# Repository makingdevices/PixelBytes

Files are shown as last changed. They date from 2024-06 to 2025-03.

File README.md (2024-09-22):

<!-- Improved compatibility of back to top link: See: https://github.com/othneildrew/Best-README-Template/pull/73 -->

<!--
*** Thanks for checking out the Best-README-Template. If you have a suggestion
*** that would make this better, please fork the repo and create a pull request
*** or simply open an issue with the tag "enhancement".
*** Don't forget to give the project a star!
*** Thanks again! Now go create something AMAZING! :D
-->

<!-- PROJECT SHIELDS -->
<!--
*** I'm using markdown "reference style" links for readability.
*** Reference links are enclosed in brackets [ ] instead of parentheses ( ).
*** See the bottom of this document for the declaration of the reference variables
*** for contributors-url, forks-url, etc. This is an optional, concise syntax you may use.
*** https://www.markdownguide.org/basic-syntax/#reference-style-links
-->
[][ig-url]
[][sponsor-url]
[][stars-url]
[][issues-url]
[][linkedin-url]

<!-- PROJECT LOGO -->
<br />
<div align="center">
  <a href="https://makingdevices.com/links/">
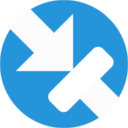
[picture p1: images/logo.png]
    
  </a>

<h3 align="center">Making Devices</h3>

  <p align="center">
    Open Source projects where we struggle with engineering, electronics, coding and who knows what else... Pixel Bytes is an evolution of my previous 8-bit console. The new version is based in the STM32F103CB with IC Leds for a colorwide screen and new power to code new games. 
  </p>
</div>

<!-- TABLE OF CONTENTS -->
<details>
  <summary>Table of Contents</summary>
  <ol>
    <li>
      <a href="#about-the-project">About The Project</a>
      <ul>
        <li><a href="#built-with">Built With</a></li>
      </ul>
    </li>
    <li>
      <a href="#Build-one">Build one</a>
      <ul>
      </ul>
    </li>
    <li><a href="#usage">Usage</a></li>
    <li><a href="#roadmap">Roadmap</a></li>
    <li><a href="#license">License</a></li>
    <li><a href="#contact">Contact</a></li>
    <li><a href="#Sponsor">Sponsor</a></li>
  </ol>
</details>

<!-- ABOUT THE PROJECT -->
## About The Project

[Bytes Counter Shot](https://makingdevices.com/)

PixelBytes was born in colaboration with Wurth Elektronik and their new RGB IC LEDs. They sent me a bunch of them to test so I though of making a proper evolution of my previous video console. For this time, I wanted to test a new manufacturer for the microcontroller, so it is my first big project working with the STM32. Hopefully it will help to develop new exciting games as it is arduino-compatible. On top of that, I decided to add a giroscope sensor so we can add more ways to have fun within the gaming experience ;). 

The project is divided into two steps: 
1. The first one is the PixelBytesDisplay, which is a matrix of 13x21 IC LEDs divided in 6 strings. 
2. The second part is the host board, which will mount the microcontroller and all the battery and sensors.

<p align="right">(<a href="#readme-top">back to top</a>)</p>

### Built With

[][PIC-url]
[][Arduino-url]
[][kicad-url]
[][sponsor-url-wurth]
[][sponsor-url]

<p align="right">(<a href="#readme-top">back to top</a>)</p>

<!-- GETTING STARTED -->

## Build one
The project is yet to be finished. Should you want to reproduce it, be careful. 

1. Get the gerber files for the latest version: [Pixel Bytes Display V0.1](/Gerber/Display/pixelbytesdisplay-v0.1) 
2. Get the gerber files for the latest version: [Pixel Bytes Host V0.1](/Gerber/Host/PixelBytesHostV0.1) 
3. Send them to a PCB manufacturer ([Our Sponsor is PCBWAY][sponsor-url])

YET TO BE COMPLETED.

<p align="right">(<a href="#readme-top">back to top</a>)</p>

<!-- USAGE EXAMPLES -->
## Usage

Instructions of use:

- When turn on, a menu is shown to select between the available games.
- Once you have played a game, a score board will appear everytime you open the game.
- You have a setting menu to turn-off the init splash and the sound.
- If you leave the console one minute without touching the buttons, it will turn into sleep mode.
- Enjoy!

<p align="right">(<a href="#readme-top">back to top</a>)</p>

<!-- ROADMAP -->
## Roadmap

- [x] Validate the Pixel Bytes Display
- [x] Assembly a prototype with the F103 Board
- [ ] Order/Assembly the Pixel Bytes Host
- [ ] Develop the firmware
  - [ ] Develop the library for the screen
  - [ ] Develop the menu 
  - [ ] Develop Snake
  - [ ] Develop Arkanoid
  - [ ] Develop Tetris
  - [ ] Develop a game that uses the gyro sensor
  - [ ] Score board
  - [ ] Sleep Mode
- [ ] Validate the complete design (host + display board)

See the [open issues](https://github.com/makingdevices/PixelBytes/issues) for a full list of proposed features (and known issues).

State: Project <b>ONGOING</b> - 22/09/2024

Priority: <b>High</b>

<p align="right">(<a href="#readme-top">back to top</a>)</p>

<!-- LICENSE -->
## License

Distributed under three licenses:
- [Hardware](/License/HW_cern_ohl_s_v2.pdf)
- [Software](/License/SW_GPLv3.0.txt)
- [Documentation](/License/Documentation_CC-BY-SA-4.0.txt)

OSHWA License: Not Finished

[GPL v3 License][license-url] 
<p align="right">(<a href="#readme-top">back to top</a>)</p>

<!-- CONTACT -->
## Contact

Making Devices - [@MakingDevices](https://www.instagram.com/makingdevices/)

Project Link: [https://github.com/makingdevices/PixelBytes](https://github.com/makingdevices/PixelBytes)

Other Links: [LinkTree](https://makingdevices.com/links/)

<!-- Sponsor -->
## Sponsors
## PCBWAY

[PCBWAY](https://www.pcbway.com/?from=makingdevices) is the most professional PCB manufacturer for prototyping and low-volume production to work with in the world. With more than a decade in the field, They are committed to meeting the needs of their customers from different industries in terms of quality, delivery, cost-effectiveness and any other demanding requests. As Sponsor of Making Devices, they will be in charge of all the PCBs for MDV, allowing both of us to grow together in a long term partnership. We hope you take them into account for your both personal and professional prototypes or products.

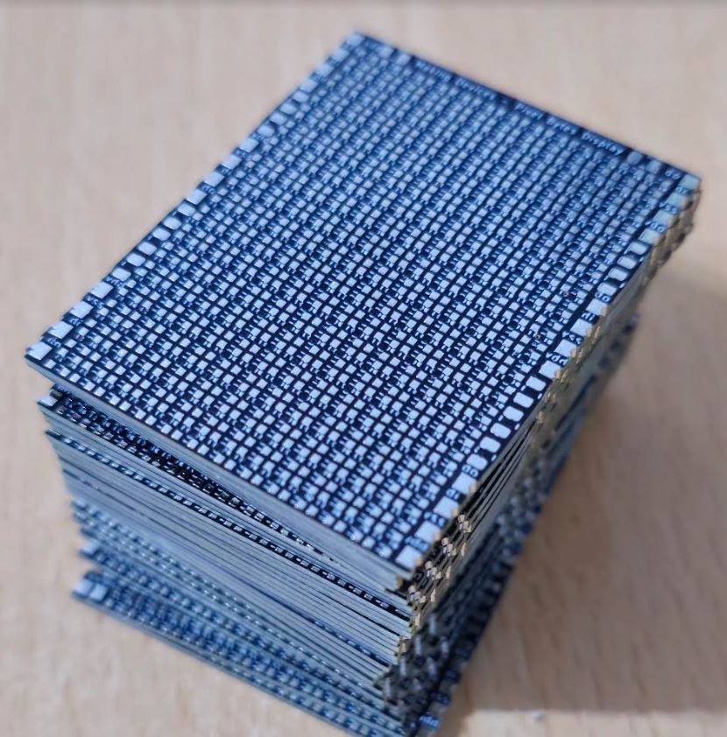
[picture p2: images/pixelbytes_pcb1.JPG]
[][sponsor-url]
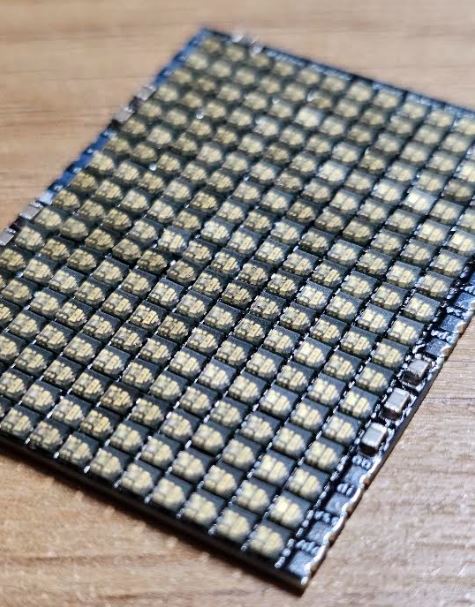
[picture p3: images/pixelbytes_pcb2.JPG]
[][sponsor-url]

## Würth Elektronik

[Wurth Elektronik](https://www.we-online.com/en) is one of the leading manufacturers of electronic and electromechanical components. The best I can say about them is to show you some pictures: All the LEDs from the board are from them. They also have buttons, resistors and capacitors that we use in all our PCBs. They also have some design kits with a lifetime refill which are amazing for makers and business so you can prototype on the go with a huge variety of components!

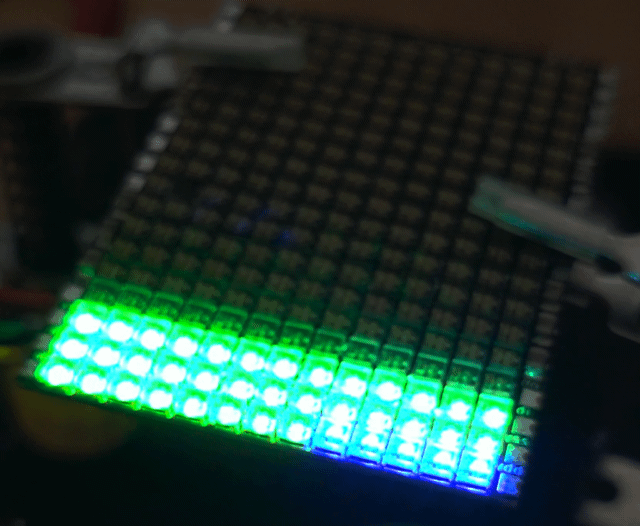
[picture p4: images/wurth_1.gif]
[][sponsor-url-wurth]
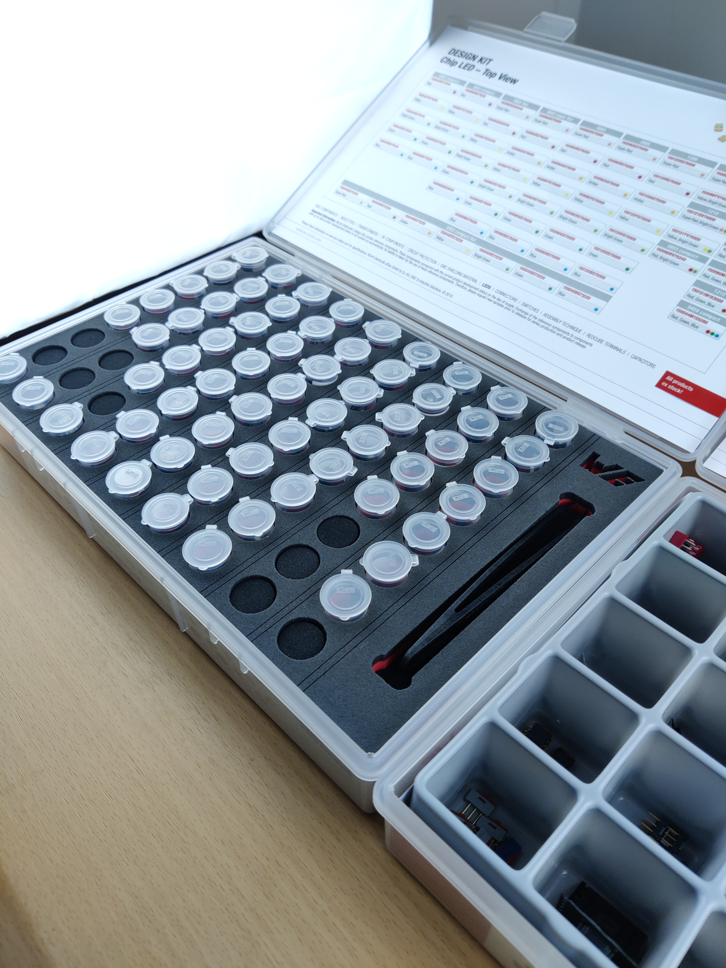
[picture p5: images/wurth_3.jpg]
[][sponsor-url-wurth]

<p align="right">(<a href="#readme-top">back to top</a>)</p>

<!-- MARKDOWN LINKS & IMAGES -->
<!-- https://www.markdownguide.org/basic-syntax/#reference-style-links -->
[contributors-shield]: https://img.shields.io/github/contributors/makingdevices/PixelBytes.svg?style=for-the-badge
[contributors-url]: https://github.com/makingdevices/PixelBytes/graphs/contributors
[forks-shield]: https://img.shields.io/github/forks/makingdevices/PixelBytes.svg?style=for-the-badge
[forks-url]: https://github.com/makingdevices/PixelBytes/network/members
[stars-shield]: https://img.shields.io/github/stars/makingdevices/PixelBytes.svg?style=for-the-badge
[stars-url]: https://github.com/makingdevices/PixelBytes/stargazers
[issues-shield]: https://img.shields.io/github/issues/makingdevices/PixelBytes.svg?style=for-the-badge
[issues-url]: https://github.com/makingdevices//PixelBytes/issues
[license-shield]: /images/license.png
[license-url]: https://github.com/makingdevices/PixelBytes/tree/main/License
[linkedin-shield]: https://img.shields.io/badge/-LinkedIn-black.svg?style=for-the-badge&logo=linkedin&colorB=555
[linkedin-url]: https://www.linkedin.com/company/making-devices/
[sponsor-shield]: https://img.shields.io/badge/SPONSOR-PCBWAY-black.svg?style=for-the-badge&colorB=1200
[sponsor-url]: https://www.pcbway.com/?from=makingdevices
[sponsor-screenshot]: /images/PCB_sponsor.png
[sponsor-pcb-1]: /images/pixelbytes_pcb1.JPG
[sponsor-pcb-2]: /images/pixelbytes_pcb2.JPG
[sponsor-wurth-1]: /images/wurth_1.gif
[sponsor-wurth-3]: /images/wurth_3.jpg
[sponsor-url-wurth]: https://www.we-online.com/en
[product-screenshot]: images/screenshot.gif
[PIC]: https://img.shields.io/badge/STM32F103-0000D1?style=for-the-badge
[PIC-url]: https://www.st.com/en/microcontrollers-microprocessors/stm32f103.html
[kicad-shield]: https://img.shields.io/badge/kicad-0b03fc?style=for-the-badge&logo=kicad&logoColor=white
[kicad-url]: https://www.kicad.org/
[YT-screenshot]: images/YT_assembly.PNG
[sponsor-icon]:  https://img.shields.io/badge/-PCBWAY-black.svg?style=for-the-badge&colorB=1200
[ig-shield]: https://img.shields.io/badge/instagram-a83297?style=for-the-badge&logo=instagram&logoColor=white
[ig-url]: https://www.instagram.com/makingdevices/
[MPLAB-C]: https://img.shields.io/badge/MPLAB%20C18-DD0031?style=for-the-badge&logo=C&logoColor=white
[Arduino]: https://img.shields.io/badge/ARDUINO-00878F?style=for-the-badge&logo=arduino&logoColor=white
[wurth-icon]: https://img.shields.io/badge/Wurth%20elektronik-FF0031?style=for-the-badge&logoColor=white
[Arduino-url]: https://www.arduino.cc/
[MPLAB-C-url]: https://www.microchip.com/en-us/development-tool/SW006011
[Svelte.dev]: https://img.shields.io/badge/Svelte-4A4A55?style=for-the-badge&logo=svelte&logoColor=FF3E00
[Svelte-url]: https://svelte.dev/
[Laravel.com]: https://img.shields.io/badge/Laravel-FF2D20?style=for-the-badge&logo=laravel&logoColor=white
[Laravel-url]: https://laravel.com
[Bootstrap.com]: https://img.shields.io/badge/Bootstrap-563D7C?style=for-the-badge&logo=bootstrap&logoColor=white
[Bootstrap-url]: https://getbootstrap.com
[JQuery.com]: https://img.shields.io/badge/jQuery-0769AD?style=for-the-badge&logo=jquery&logoColor=white
[JQuery-url]: https://jquery.com

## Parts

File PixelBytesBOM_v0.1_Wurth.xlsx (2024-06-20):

Part | Info | Qty. | Boards | Total Qty | Link
STM32F103CBT6TR | STM32 microcontroller | 1 | 5 | 5 | https://eu.mouser.com/ProductDetail/STMicroelectronics/STM32F103CBT6TR?qs=SU4Xa%252BYHGQr0GBvhN6Y2ig%3D%3D
Nucleo Board F103RB | F103 Dev Board | 1 |  | 1 | https://eu.mouser.com/ProductDetail/STMicroelectronics/NUCLEO-F103RB?qs=fK8dlpkaUMs2W6dqxUbL2w%3D%3D
Magi3c | Step Down | 1 | 5 | 5 | Order Code: 171040302
MagI3C | Step Down development board | 1 |  | 1 | Order Code: 178040302
IC Leds 2020 | Chip Led 2020 | 230 | 5 | 1150 | Order Code: 1312020030000
Pin Headers 12x2.54mm |  | 1 | 5 | 5 | Order Code: 61301211121
SMT socket 2.54mm |  | 4 | 5 | 20 | Order Code: 61000411921
Socket 2.54mm |  | 4 | 5 | 20 | Order Code: 61300411821
Switch SMD 2.54mm 1pole |  | 4 | 5 | 20 | Order Code: 418121270801
Buttons |  | 6 | 5 | 30 | Order Code: 430182050816
Slider |  | 1 | 5 | 5 | Order Code: 450302014072
Gyroscope | 3-axis gyroscope WSEN-ISDS | 1 | 5 | 5 | Order Code: 2536030320001
USB Type C |  | 1 | 5 | 5 | Order Code: 629722000214
Liter Energy Battery - 503450 | -- Select JST PH 2.5mm 3 Pin NTC if possible -- | 1 | 5 | 5 | https://www.bihuade.com/products/503450-37v-1000mah-liter-energy-battery-lithium-polymer-lipo-rechargeable-battery-li-ion-cells-with-2pin-ph-20mm-plug

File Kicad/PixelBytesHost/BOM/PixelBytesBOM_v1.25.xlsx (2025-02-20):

Designator | Value | Package | Notes | Manufacturer / Distributor | Part number | Total | Price | Total Price | Link to distributor
C1,C2 | 4.7 µF | 0805 | - | Würth Elektronik | 885012207053 | 2 |  | 0.00 €
C3,C4,C5,C6,C9,C10,C11,C12,C13,C14,C16,C17,C20 | 100 nF | 0805 | - | Würth Elektronik | 885012207045 | 13 |  | 0.00 €
C7,C8 | 22 pF | 0805 | - | Würth Elektronik | 885012007012 | 2 |  | 0.00 €
C15 | 10 µF | 0805 | - | Würth Elektronik | 885012107014 | 1 |  | 0.00 €
C18 | 820 pF | 0805 | - | Mouser | 581-0805YC821KAT2A | 1 | 0.26 € | 0.26 € | https://www.mouser.de/ProductDetail/KYOCERA-AVX/0805YC821KAT2A?qs=6ozWKCQkT2Xkw%2FNtqDQHOw%3D%3D
C19 | 22 µF | 0805 | - | Würth Elektronik | 885012107011 | 1 |  | 0.00 €
C21 | 47 µF | 0805 | - | Würth Elektronik | 885012107006 | 1 |  | 0.00 €
D1 |  | SMA-2 | - | Mouser | 621-B340LA-F | 1 | 0.41 € | 0.41 € | https://www.mouser.de/ProductDetail/Diodes-Incorporated/B340LA-13-F?qs=dU8xVB810ithG3OzkYQiSg%3D%3D
IC1 |  |  | - | Würth Elektronik | 2536030320001 | 1 |  | 0.00 €
IC2 |  | SOT-223-3 | - | Mouser | 579-TC1108-3.3VDBTR | 1 |  | 0.00 € | https://www.mouser.de/ProductDetail/Microchip-Technology/TC1108-3.3VDBTR?qs=AIv3GLl6KMNgHSi6BcHPMA%3D%3D
IC3 |  | VSSOP-8 | - | Mouser | TPS61085TDGKR | 1 | 2.09 € | 2.09 € | https://www.mouser.de/ProductDetail/Texas-Instruments/TPS61085TDGKR?qs=%2Fqzd9s%252BcLd4U2Z7ineHARw%3D%3D
IC_BMS_TP1 |  |  | TP4056 | LCSC | TP4056-42-ESOP8 | 1 |  | 0.00 €
J1 |  |  | TC2030-MCP-NL | RS |  | 1 |  | 0.00 € | http://uk.rs-online.com/web/p/products/8252561
J3 |  | USB 2.0 Type C | - | Würth Elektronik | 629722000214 | 1 |  | 0.00 €
J2 |  |  | Depends on the battery! | Digikey | B2B-PH-K-S(LF)(SN) | 1 | 0.11 € | 0.11 € | https://eu.mouser.com/ProductDetail/JST-Commercial/B2B-PH-K-SLFSN?qs=cdbOS8ANM9AlozzPlOt72g%3D%3D
JP1,JP2 |  |  | Do not solder JP1 -> reset the microcontroller. JP2 -> It turns ON the display even if the circuitry of Q3 does not work. |  |  | 2 |  | 0.00 €
L1 | 4.7 µH | 6045 | - | Würth Elektronik | 74404064470 | 1 |  | 0.00 €
LED_green_bms1, LED_green_bms2 |  | 0805 | - | Würth Elektronik | 150080VS75000 | 2 |  | 0.00 €
LED_Red_bms1 |  | 0805 | - | Würth Elektronik | 150080RS75000 | 1 |  | 0.00 €
LS1 |  | 12 mm x 9.5 mm THT |  | Mouser | 497-IE122305-7 | 1 | 1.84 € | 1.84 €
Q1,Q2 |  | SOT-23-3 | - | Mouser | 863-SMMBT5551LT1G | 2 | 0.18 € | 0.35 € | https://www.mouser.de/ProductDetail/onsemi/SMMBT5551LT1G?qs=pqrSHODkHouUw%252BkpWZRtSg%3D%3D
Q3 |  | SOT-23-3 | - | Mouser | PBSS5160T-QR | 1 | 0.36 € | 0.36 € | https://eu.mouser.com/ProductDetail/Nexperia/PBSS5160T-QR?qs=Wj%2FVkw3K%252BMDs0Mh98%252BXOSA%3D%3D
R1,R4 | 4.7 k | 0805 | - | Mouser | 652-CRS0805FX4701ELF | 2 | 0.20 € | 0.39 € | https://www.mouser.de/ProductDetail/Bourns/CRS0805-FX-4701ELF?qs=5aG0NVq1C4zi3u8a2fn%2F4A%3D%3D
R8 | 1.5 k | 0805 | - | Mouser | 603-AC0805FR-7W1K5L | 1 | 0.12 € | 0.12 € | https://www.mouser.de/ProductDetail/YAGEO/AC0805FR-7W1K5L?qs=tggtontpCXOnFNPPSnV6UQ%3D%3D
R2, R3, R5, R6, R7, R9, R10, R11, R12, R13, R14, R15, R16, R17, R18, R19, R20, R31 | 10 k | 0805 | - | Würth Elektronik | 560112120004 | 18 |  | 0.00 €
R30 | 3K3 | 0805 | - | Würth Elektronik | 560112120029 | 1 |  | 0.00 €
R21 | 2 k | 0805 | - | Mouser | 71-RCC08052K00FKEA | 1 | 0.17 € | 0.17 € | https://www.mouser.de/ProductDetail/Vishay-Dale/RCC08052K00FKEA?qs=GedFDFLaBXEsPPGyfAdG1g%3D%3D
R22 | 6k8 | 0805 |  | Würth Elektronik | 560112120031 | 1
R23,R24, R32 | 1 k | 0805 | - | Mouser | 652-CRS0805FX1001ELF | 3 | 0.20 € | 0.58 € | https://www.mouser.de/ProductDetail/Bourns/CRS0805-FX-1001ELF?qs=3ZbGupGMFUdZykYWZvWIOw%3D%3D
R25,R29 | 5.1 k | 0805 | - | Würth Elektronik | 560112120019 | 2 |  | 0.00 €
R26 | 44.2 k | 0805 | - | Mouser | 660-RK73H2ATTD4422F | 1 | 0.10 € | 0.10 € | https://www.mouser.de/ProductDetail/KOA-Speer/RK73H2ATTD4422F?qs=m6PtEeoja6gXuxdF67JveA%3D%3D
R27 | 100 k | 0805 |  | Würth Elektronik | 560112120013 | 1
R28 | 38,3 k | 0805 |  | Mouser | CR0805-FX-3832ELF | 1 | 0.10 € | 0.10 € | https://eu.mouser.com/ProductDetail/Bourns/CR0805-FX-3832ELF?qs=TYKCbaKwe1BbGRAYPT34xA%3D%3D
SW_Toggle1 |  |  |  | Würth Elektronik | 450302014072 | 1 |  | 0.00 €
S_a1,S_b1,S_down1,S_left1,S_right1,S_up1 |  | 6x6 mm |  | Würth Elektronik | 430182050816 | 6 |  | 0.00 €
S1 |  |  |  | Würth Elektronik | 434121025816 | 1 |  | 0.00 €
U1 | Pixel Bytes Display | - | - | - | - | 1 |  | 0.00 €
U2 |  | LQFP-48 |  | Mouser | 511-STM32F103CBT6TR | 1 | 5.78 € | 5.78 € | https://eu.mouser.com/ProductDetail/STMicroelectronics/STM32F103CBT6TR?qs=SU4Xa%252BYHGQr0GBvhN6Y2ig%3D%3D
Y1 | 8Mhz |  |  | Würth Elektronik | 830055663 | 1 |  | 0.00 €
 |  |  |  |  | Total | 82 |  | 12.66 €
Tested Battery: | https://www.amazon.com/EEMB-1100mAh-Battery-Rechargeable-Connector/dp/B08VRYS8FT?th=1

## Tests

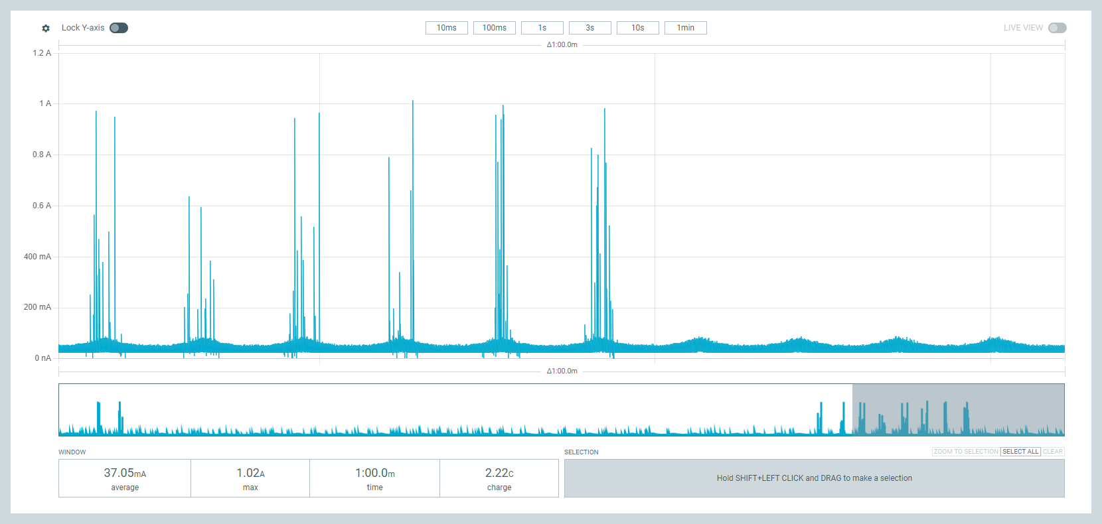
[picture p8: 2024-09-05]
Validation/Display/CurrentConsumptionV0.1_group6_1color_10pwm3.6VSupply.png

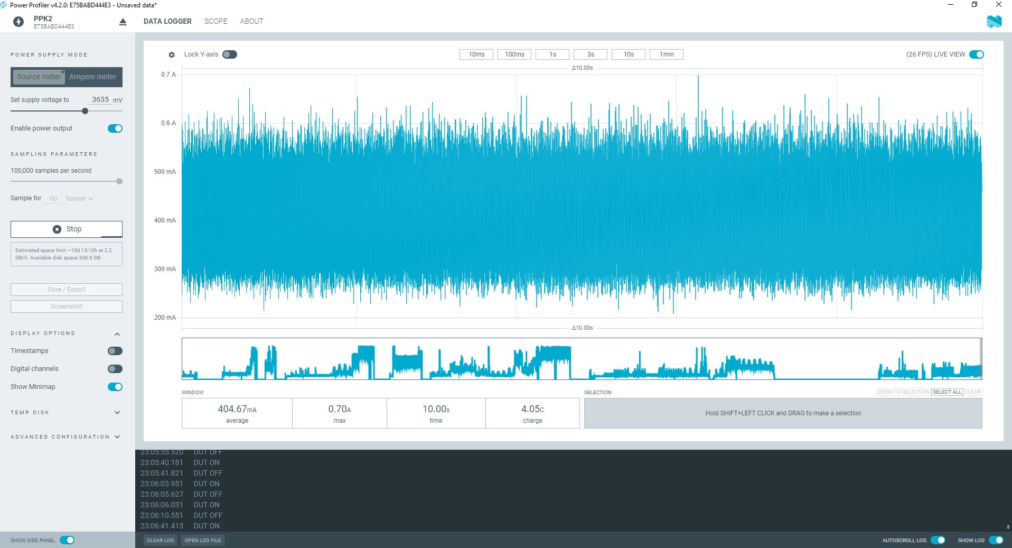
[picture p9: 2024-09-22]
Validation/Display/consumo_pixel_bytes_display_3.6V_white_234_LEDs_20brightness.JPG

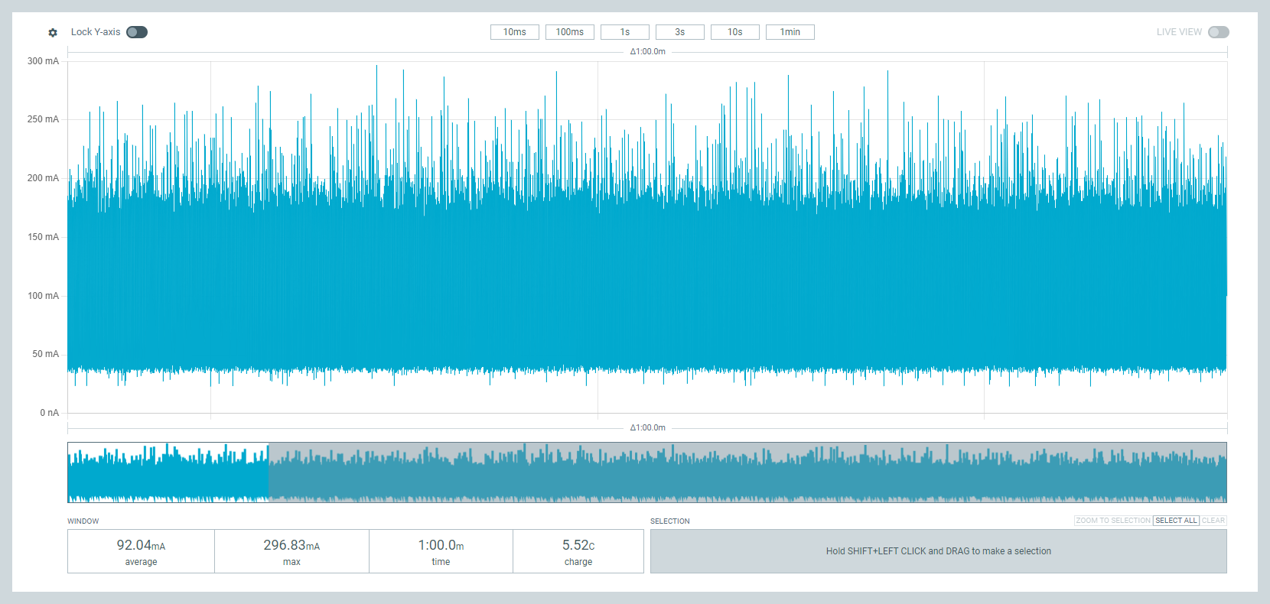
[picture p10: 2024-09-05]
Validation/Display/CurrentConsumptionV0.1_group6_3color_30pwm_3.6VSupply.png

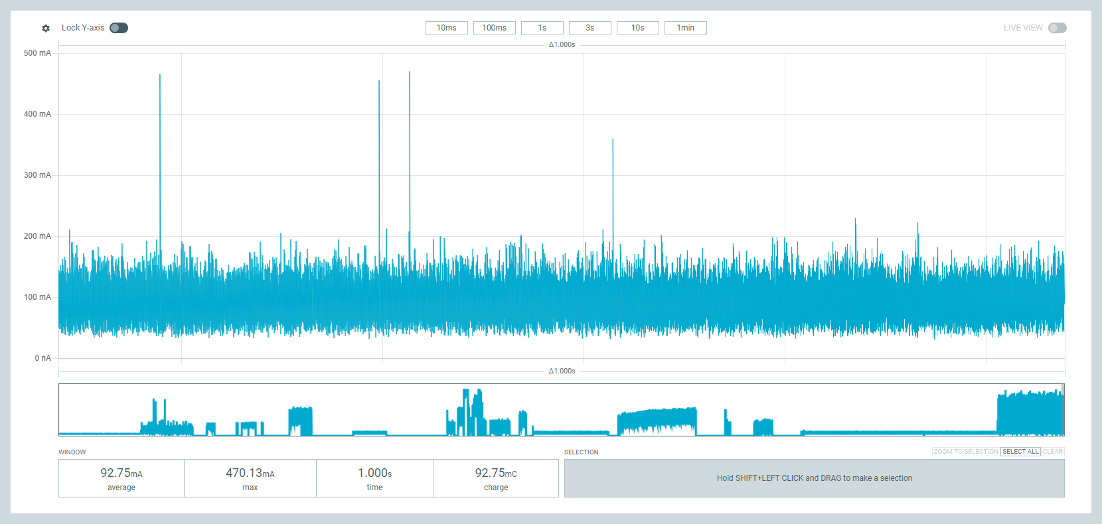
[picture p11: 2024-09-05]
Validation/Display/CurrentConsumptionV0.1_group6_3color_30pwm_3.6VSupply_new.png

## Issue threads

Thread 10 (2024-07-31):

Bootloader

makingdevices, 2024-07-31:
**Design:**

- [ ] The STM32 should have a bootloader on it.
- [ ] The device can be programmed using arduino IDE from the usb type C

**To validate:**

- [ ] The arduino IDE recognize the device and it can be programmed

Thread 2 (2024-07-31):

Battery

makingdevices, 2024-07-31:
**Design:**

- [] Pouch Li-ion battery (1 cell).
- [] 3.6V power supply for the display and all the electronics.
- [] 5.0V USB type-C input voltage.
- [] There are Two lights: 1 for charging and 1 for input voltage.
- [] You can read the SoC of the battery without current leakage.

**Validate:**

- [] There is a switch to turn on-off the device (disconnects all the power after the battery).
- [] You can charge the battery while playing.
- [] You should be able to read the State of Charge of the battery.
- [] At least 20min lifetime with any game.
- [] When you plug the device, the light for the input voltage is ON.
- [] When you are chargind the battery, the battery indicator is ON.

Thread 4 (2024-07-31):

Sound

makingdevices, 2024-07-31:
The videoconsole should be able to play basic sound notes with the buzzer.

Design:

- [ ] The PWM is connected to the buzzer and can be used to control some music tones.

Validate:

- [ ] The music works with the games
- [ ] It should be a Settings menu for muting the buzzer (or unmute)

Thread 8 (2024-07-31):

Assembly Pixel Bytes Display v0.1

makingdevices, 2024-07-31:
- [x] Receive all the components
- [ ] Assembly the first iteration
- [ ] Check that all LEDs works OK.

makingdevices, 2024-10-14:
Display tested and working. They are quite fragile so be careful when assembling

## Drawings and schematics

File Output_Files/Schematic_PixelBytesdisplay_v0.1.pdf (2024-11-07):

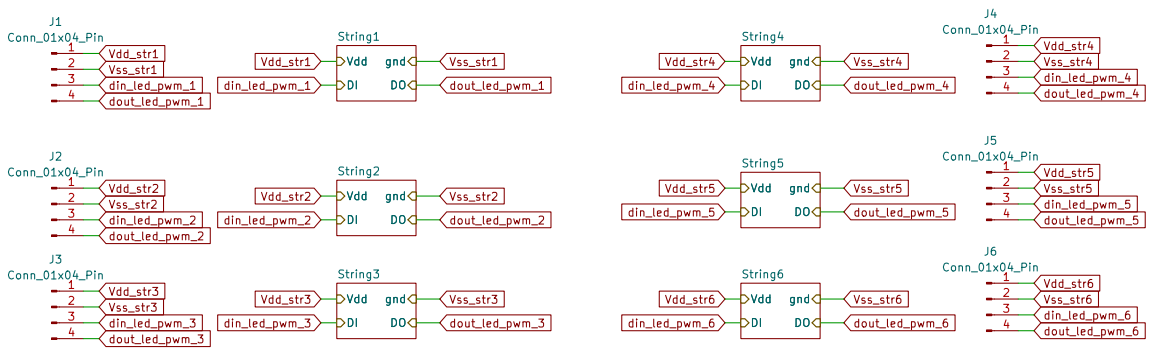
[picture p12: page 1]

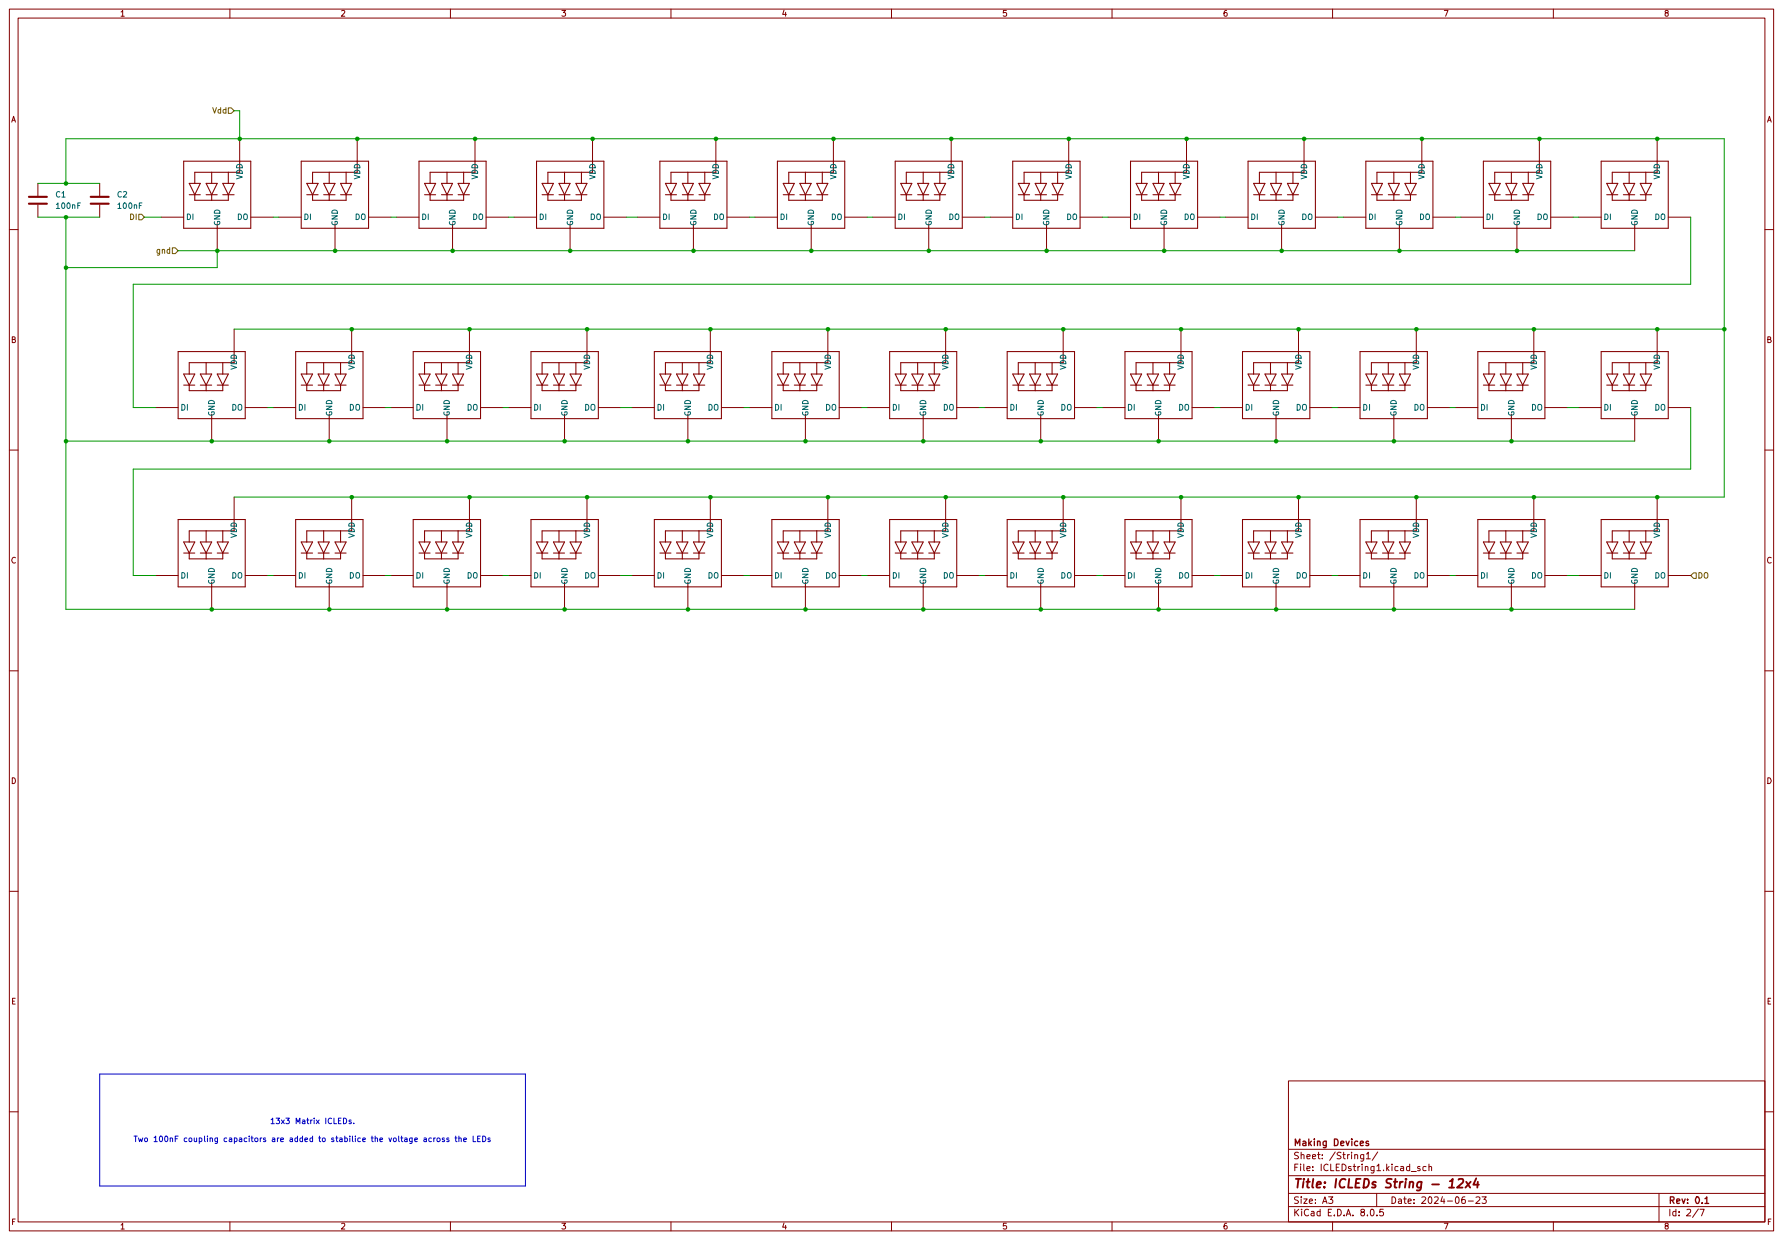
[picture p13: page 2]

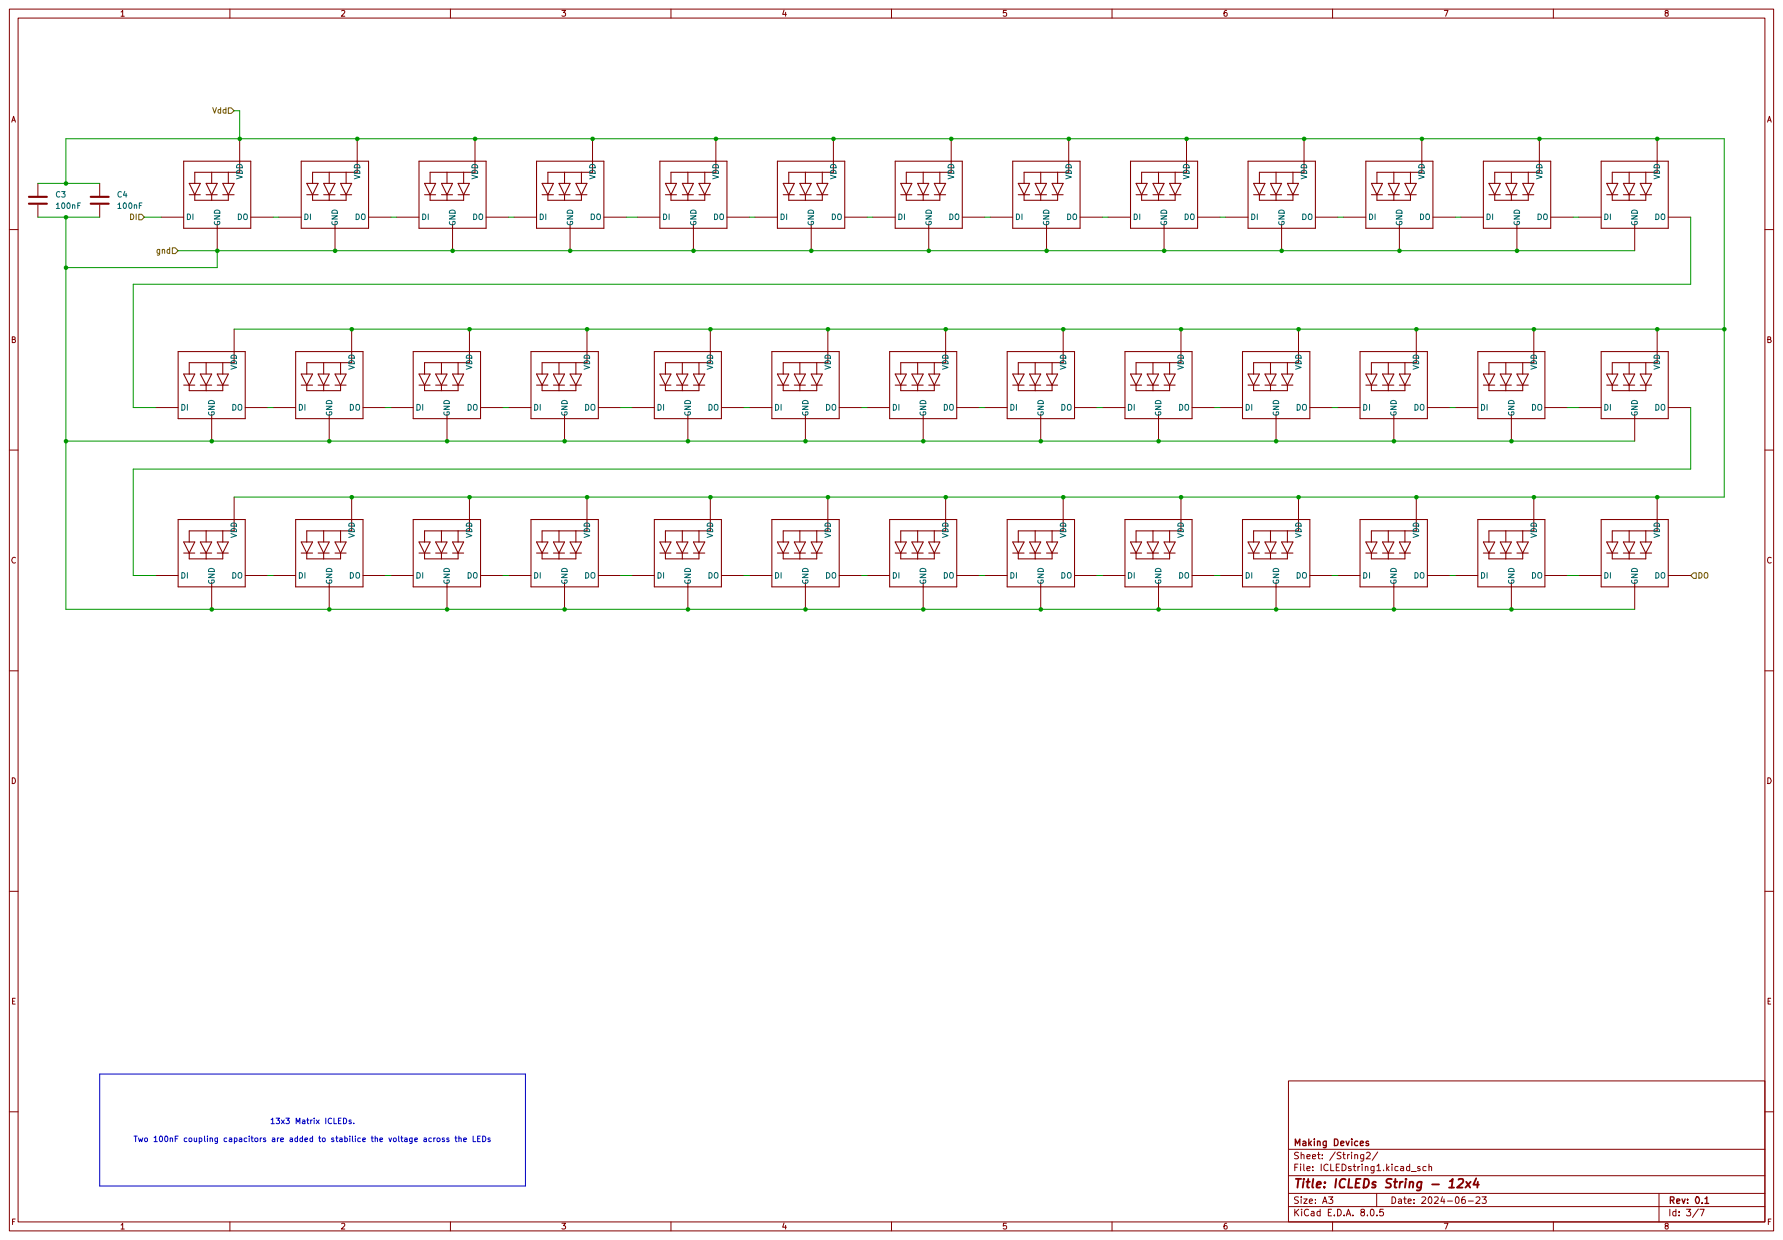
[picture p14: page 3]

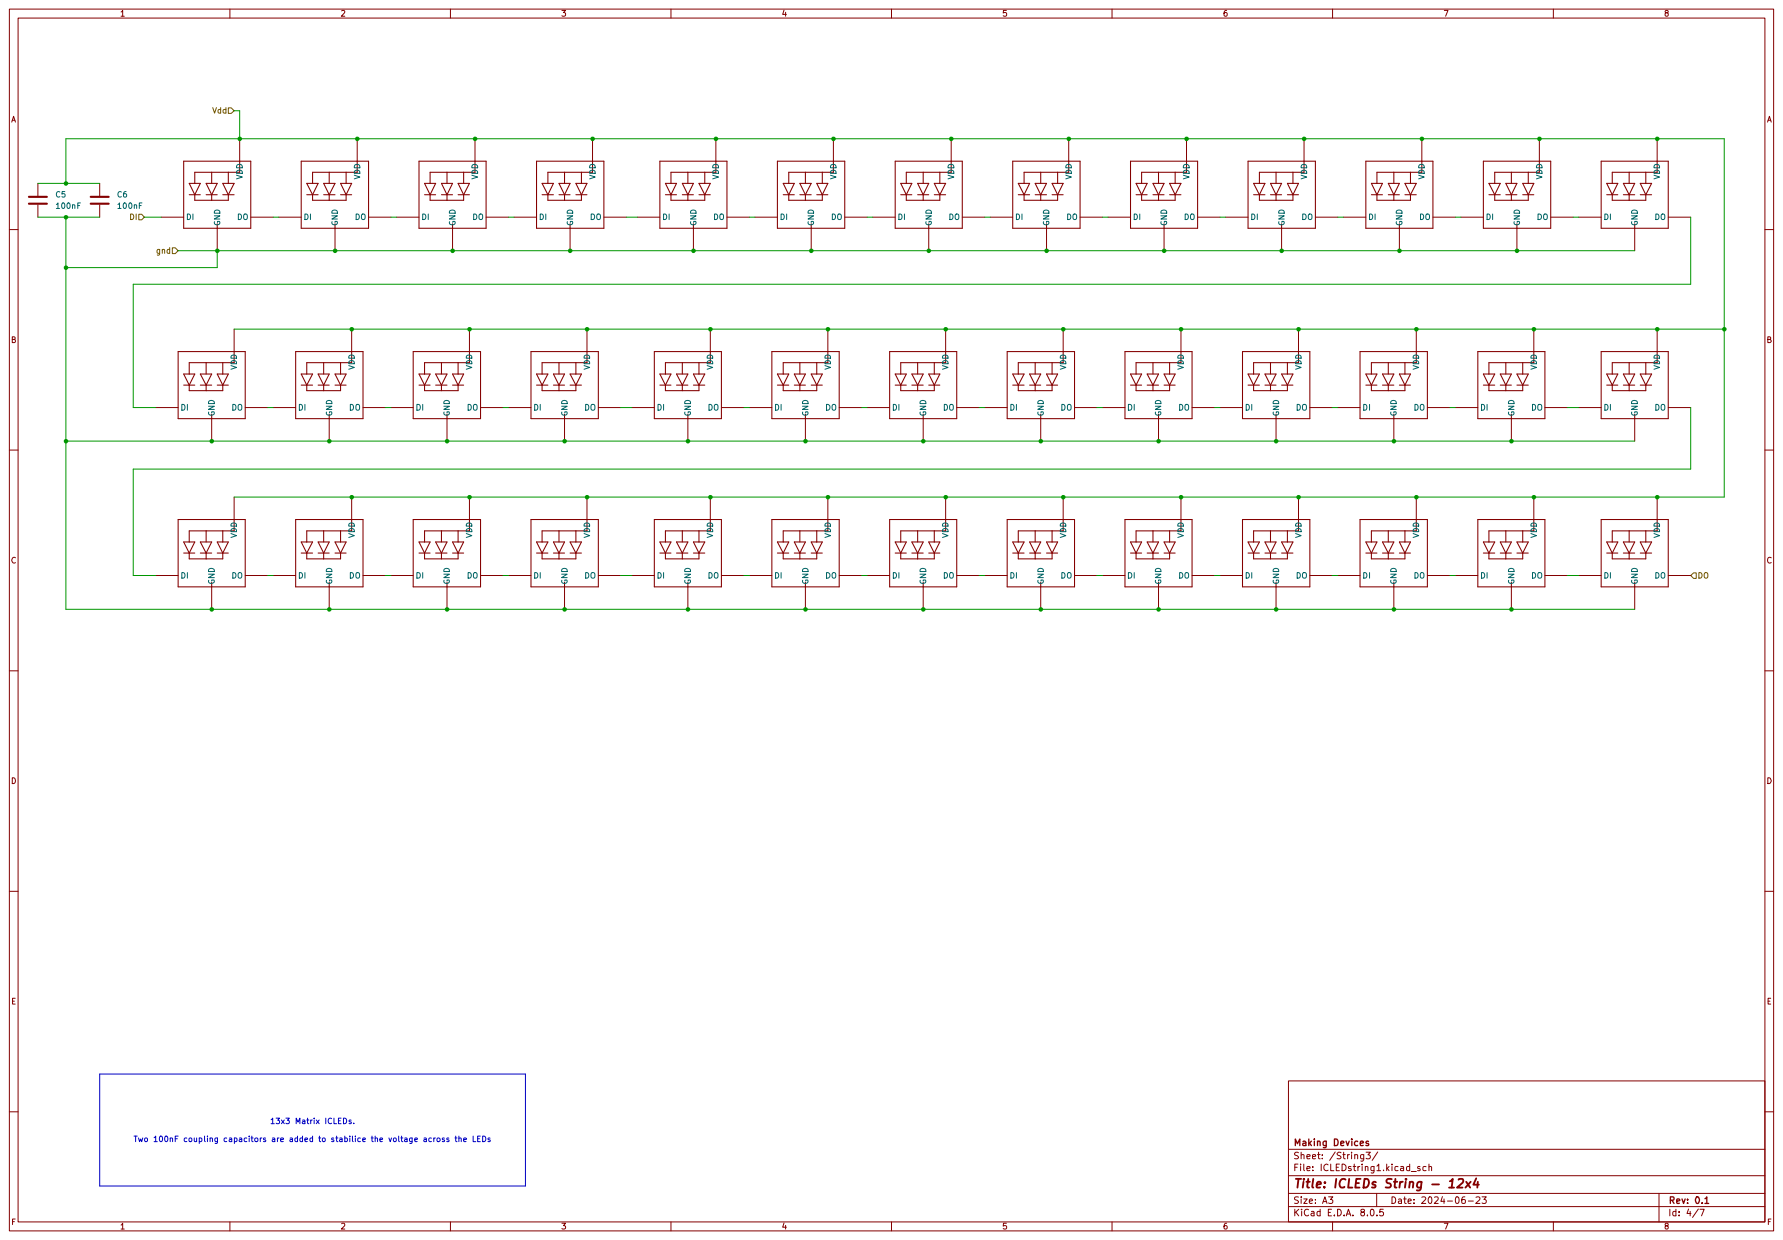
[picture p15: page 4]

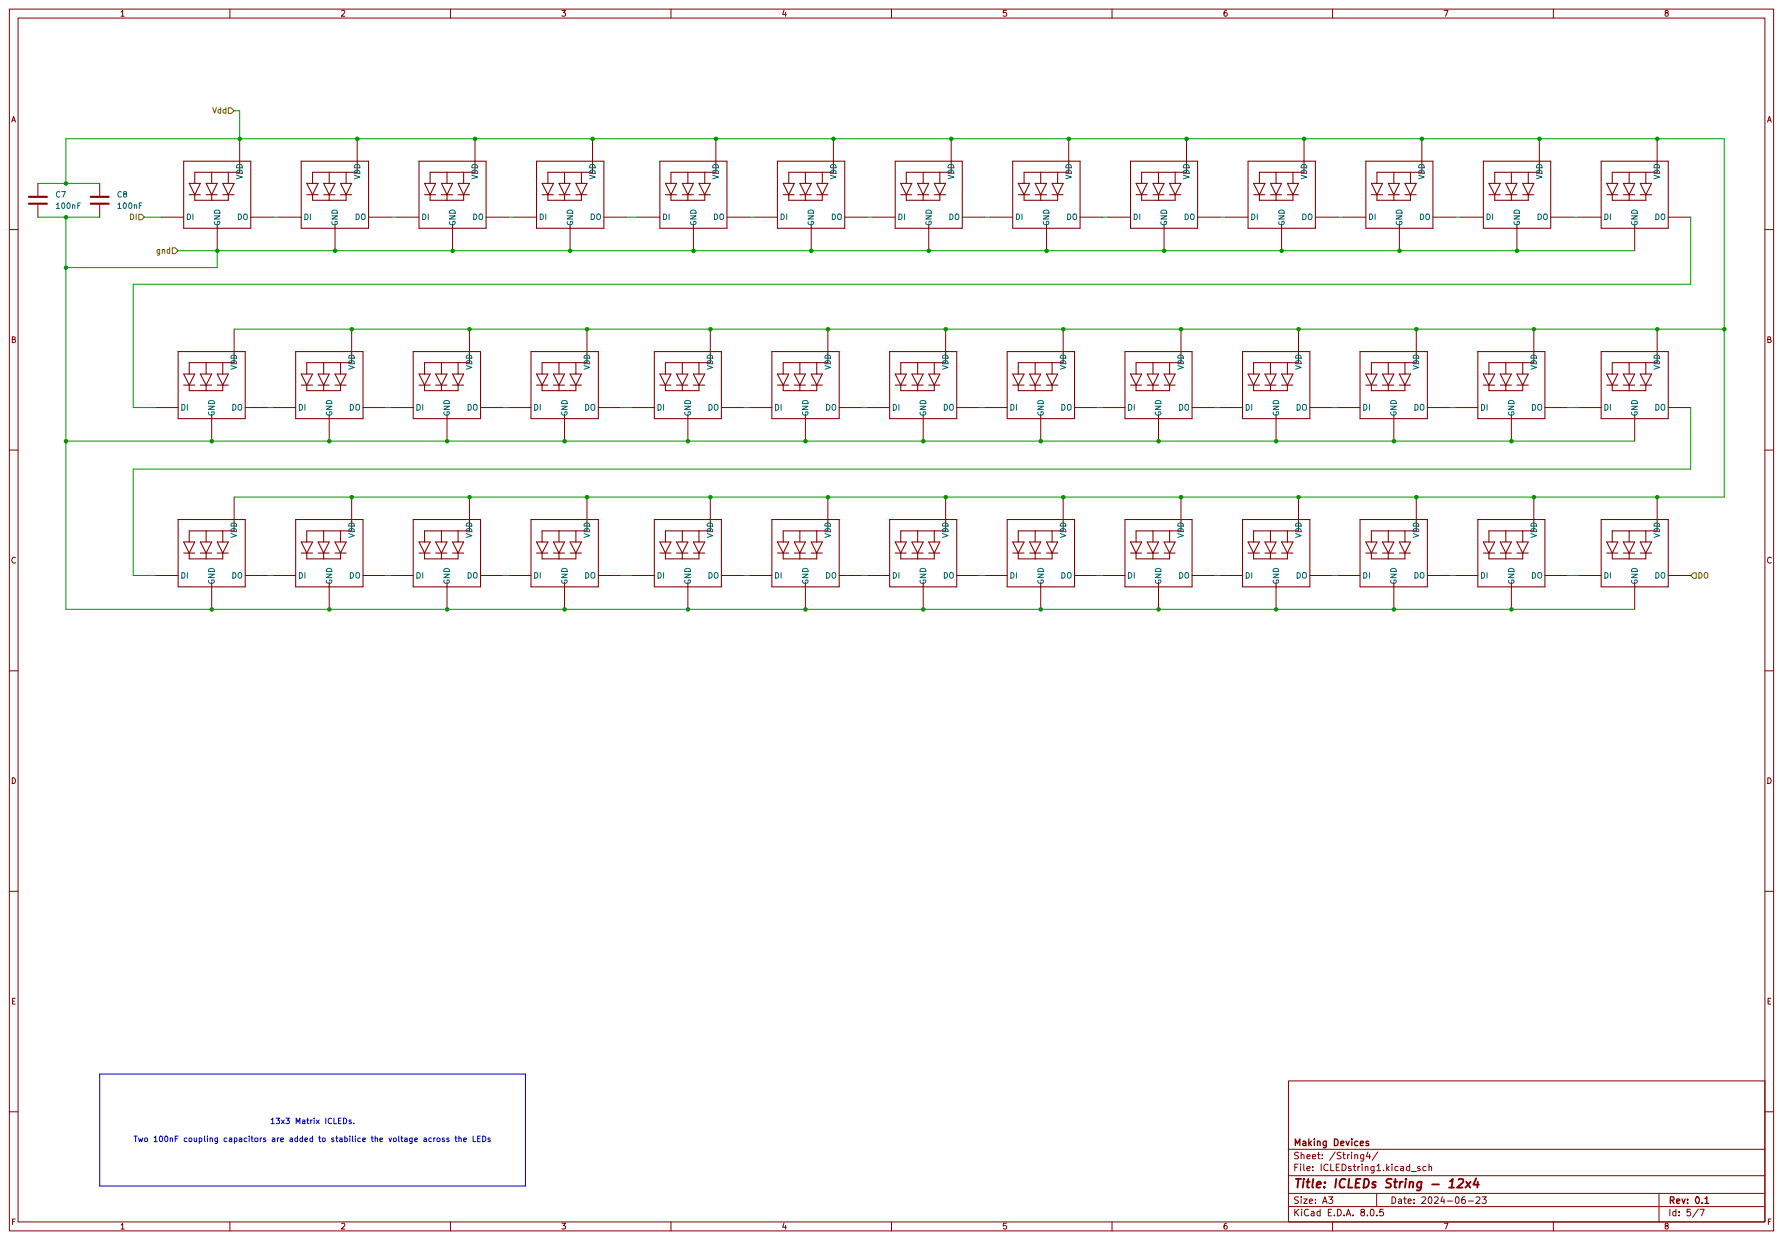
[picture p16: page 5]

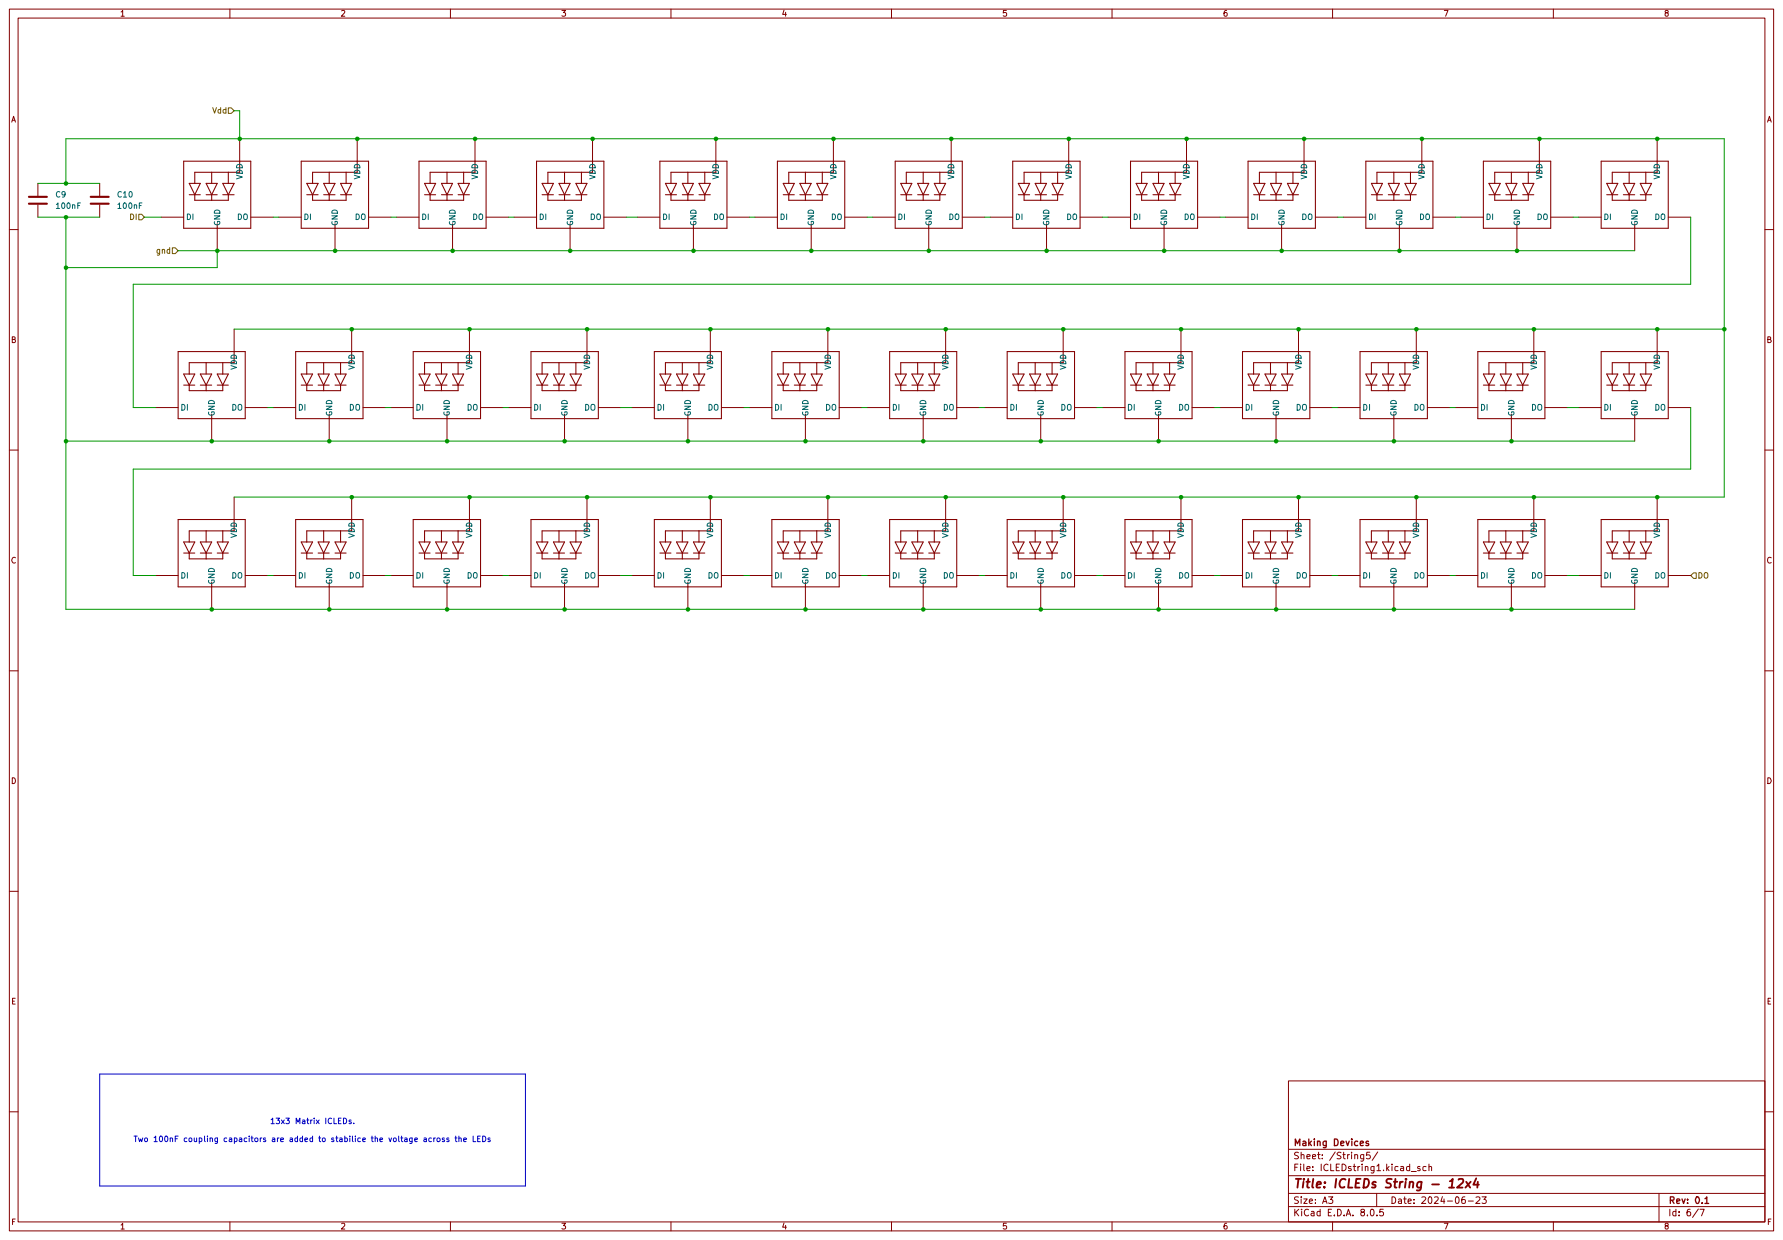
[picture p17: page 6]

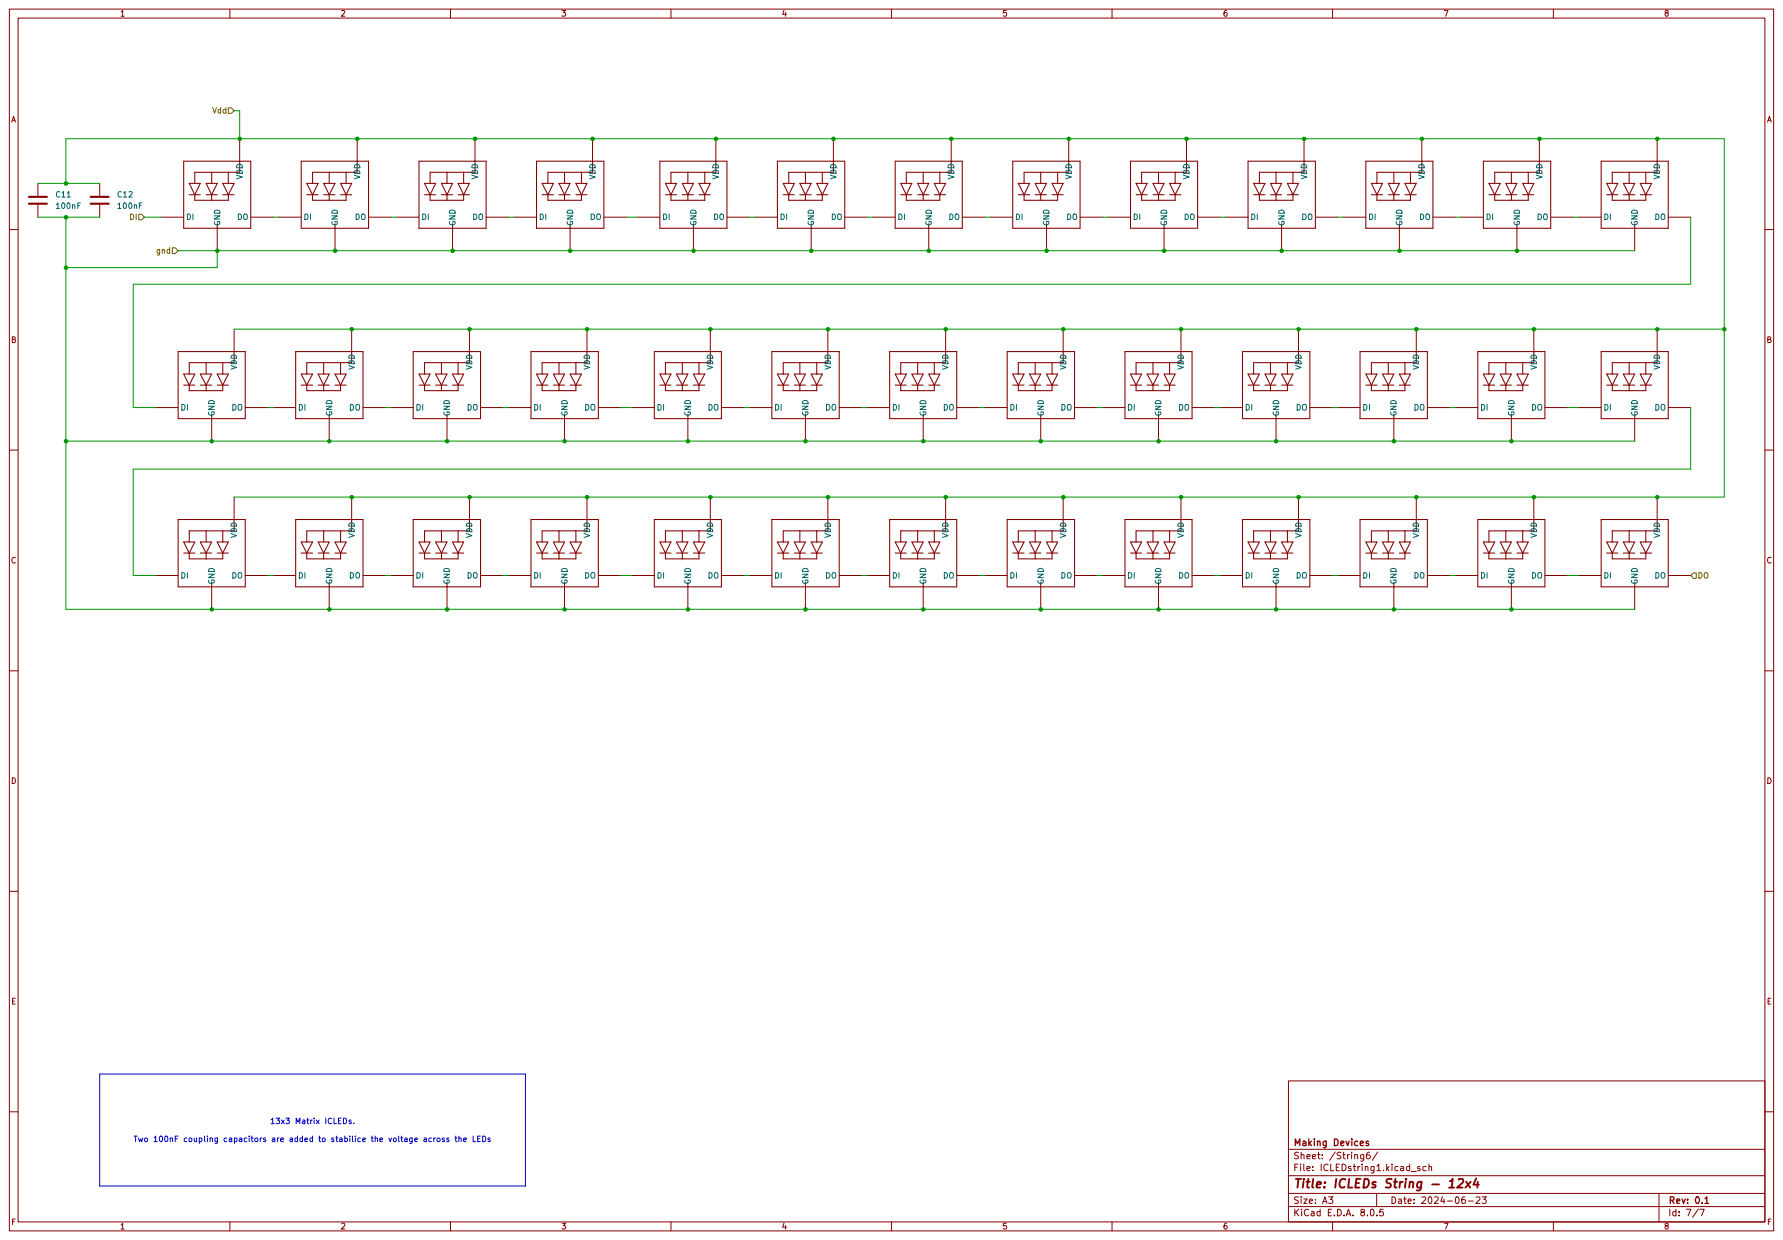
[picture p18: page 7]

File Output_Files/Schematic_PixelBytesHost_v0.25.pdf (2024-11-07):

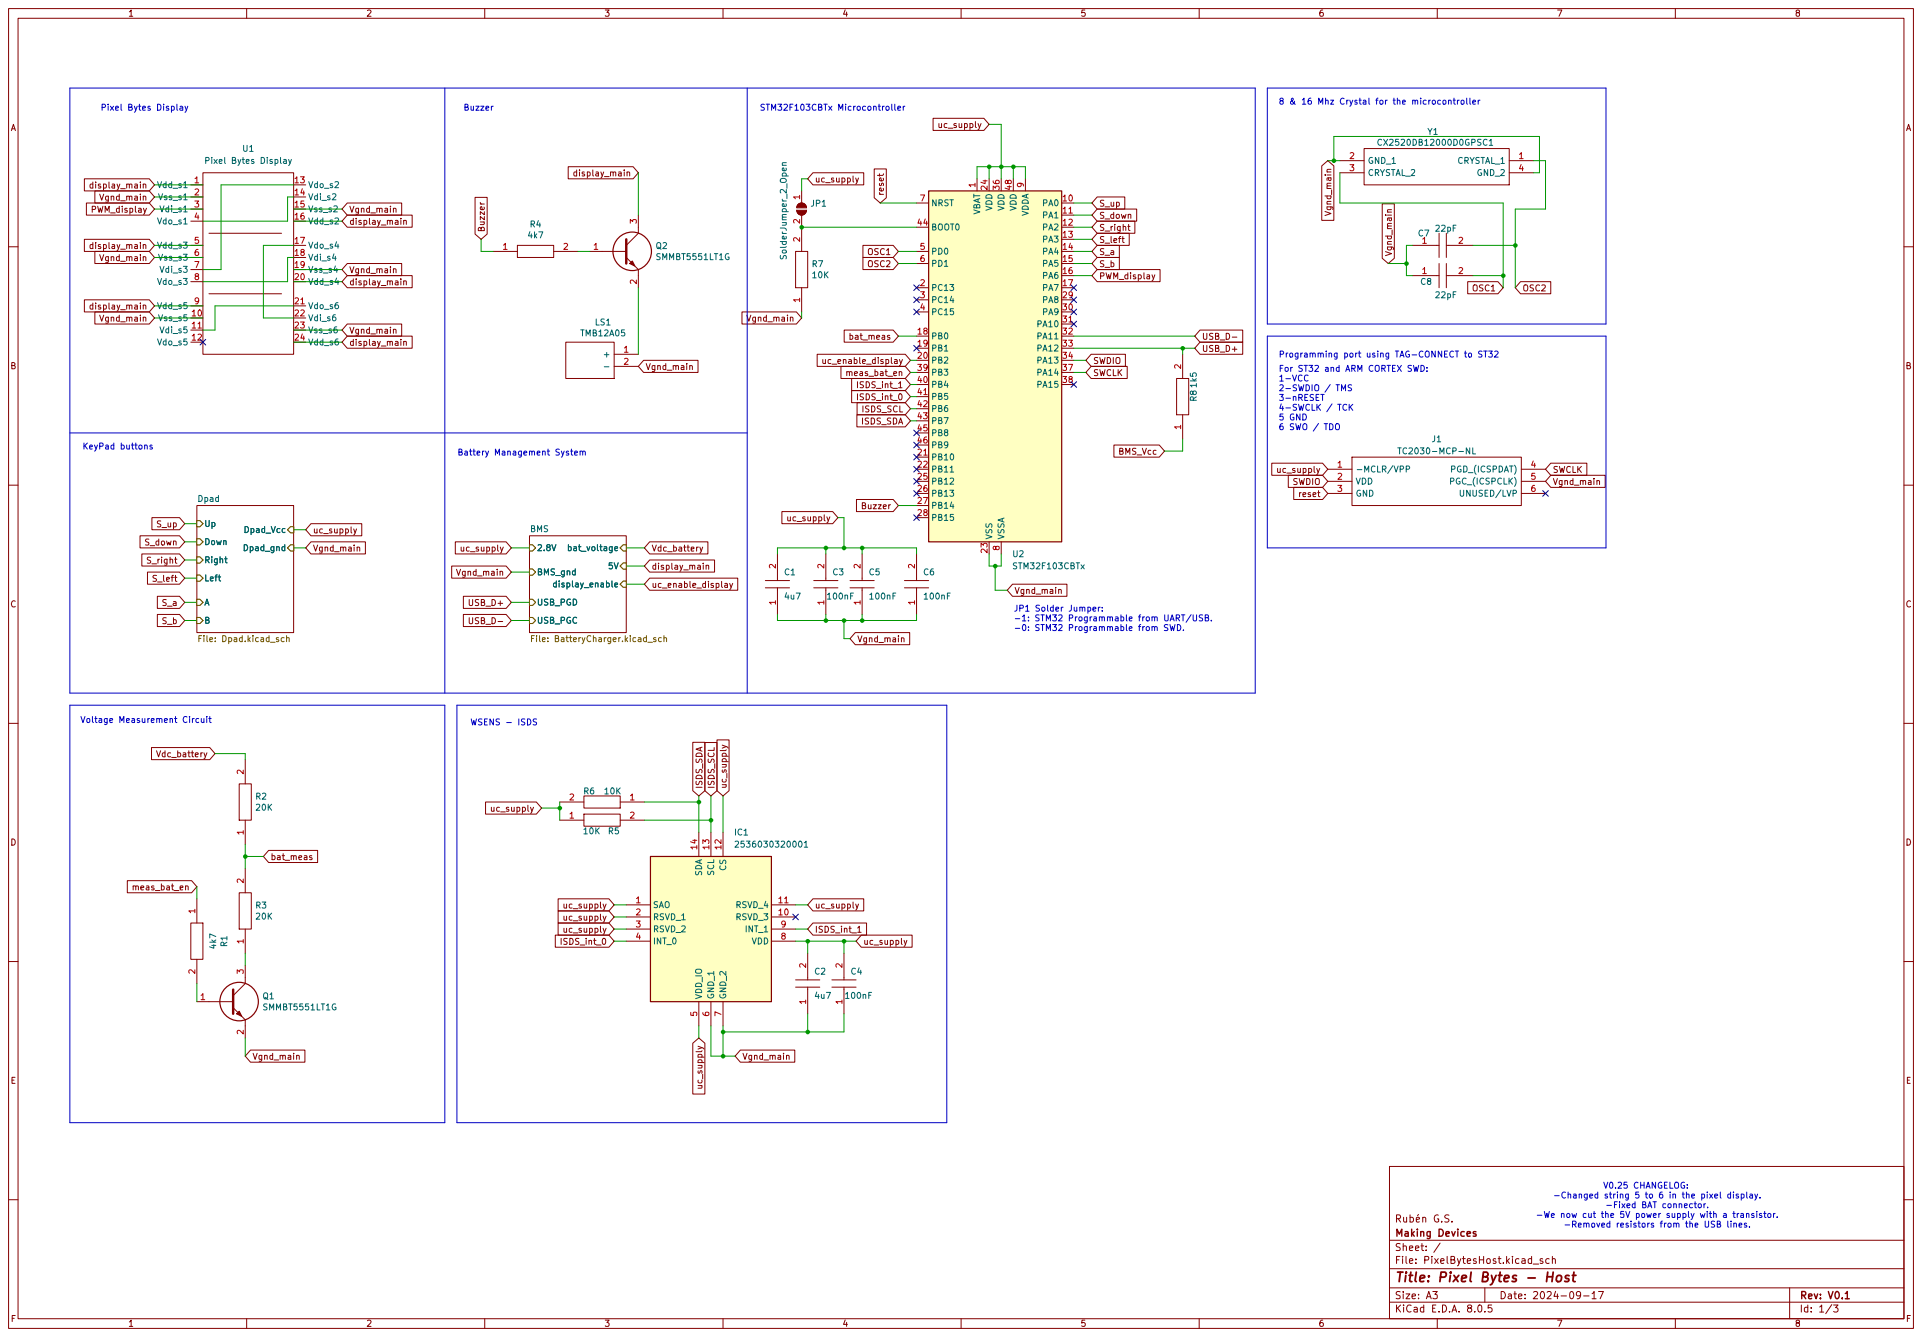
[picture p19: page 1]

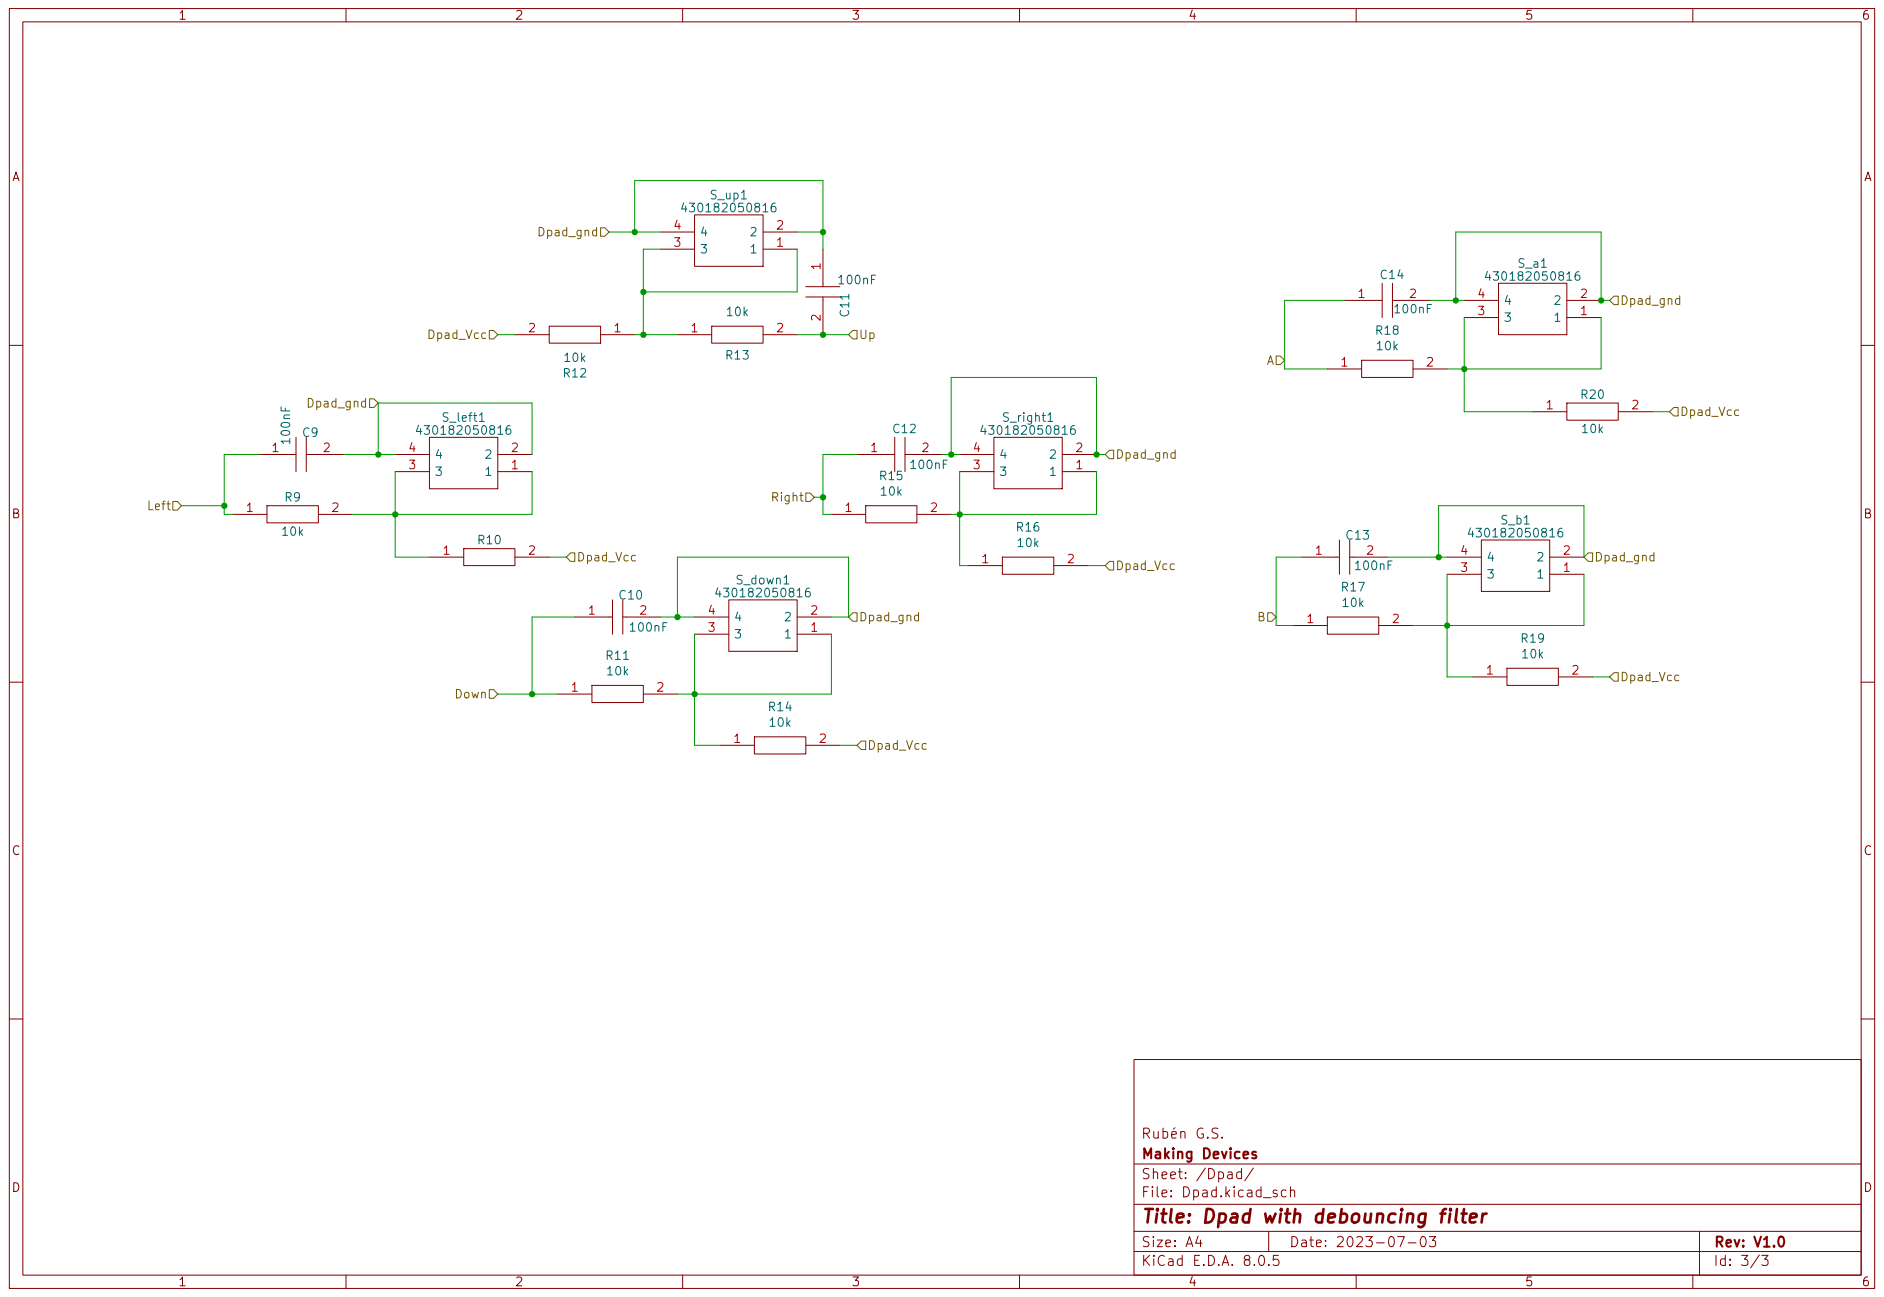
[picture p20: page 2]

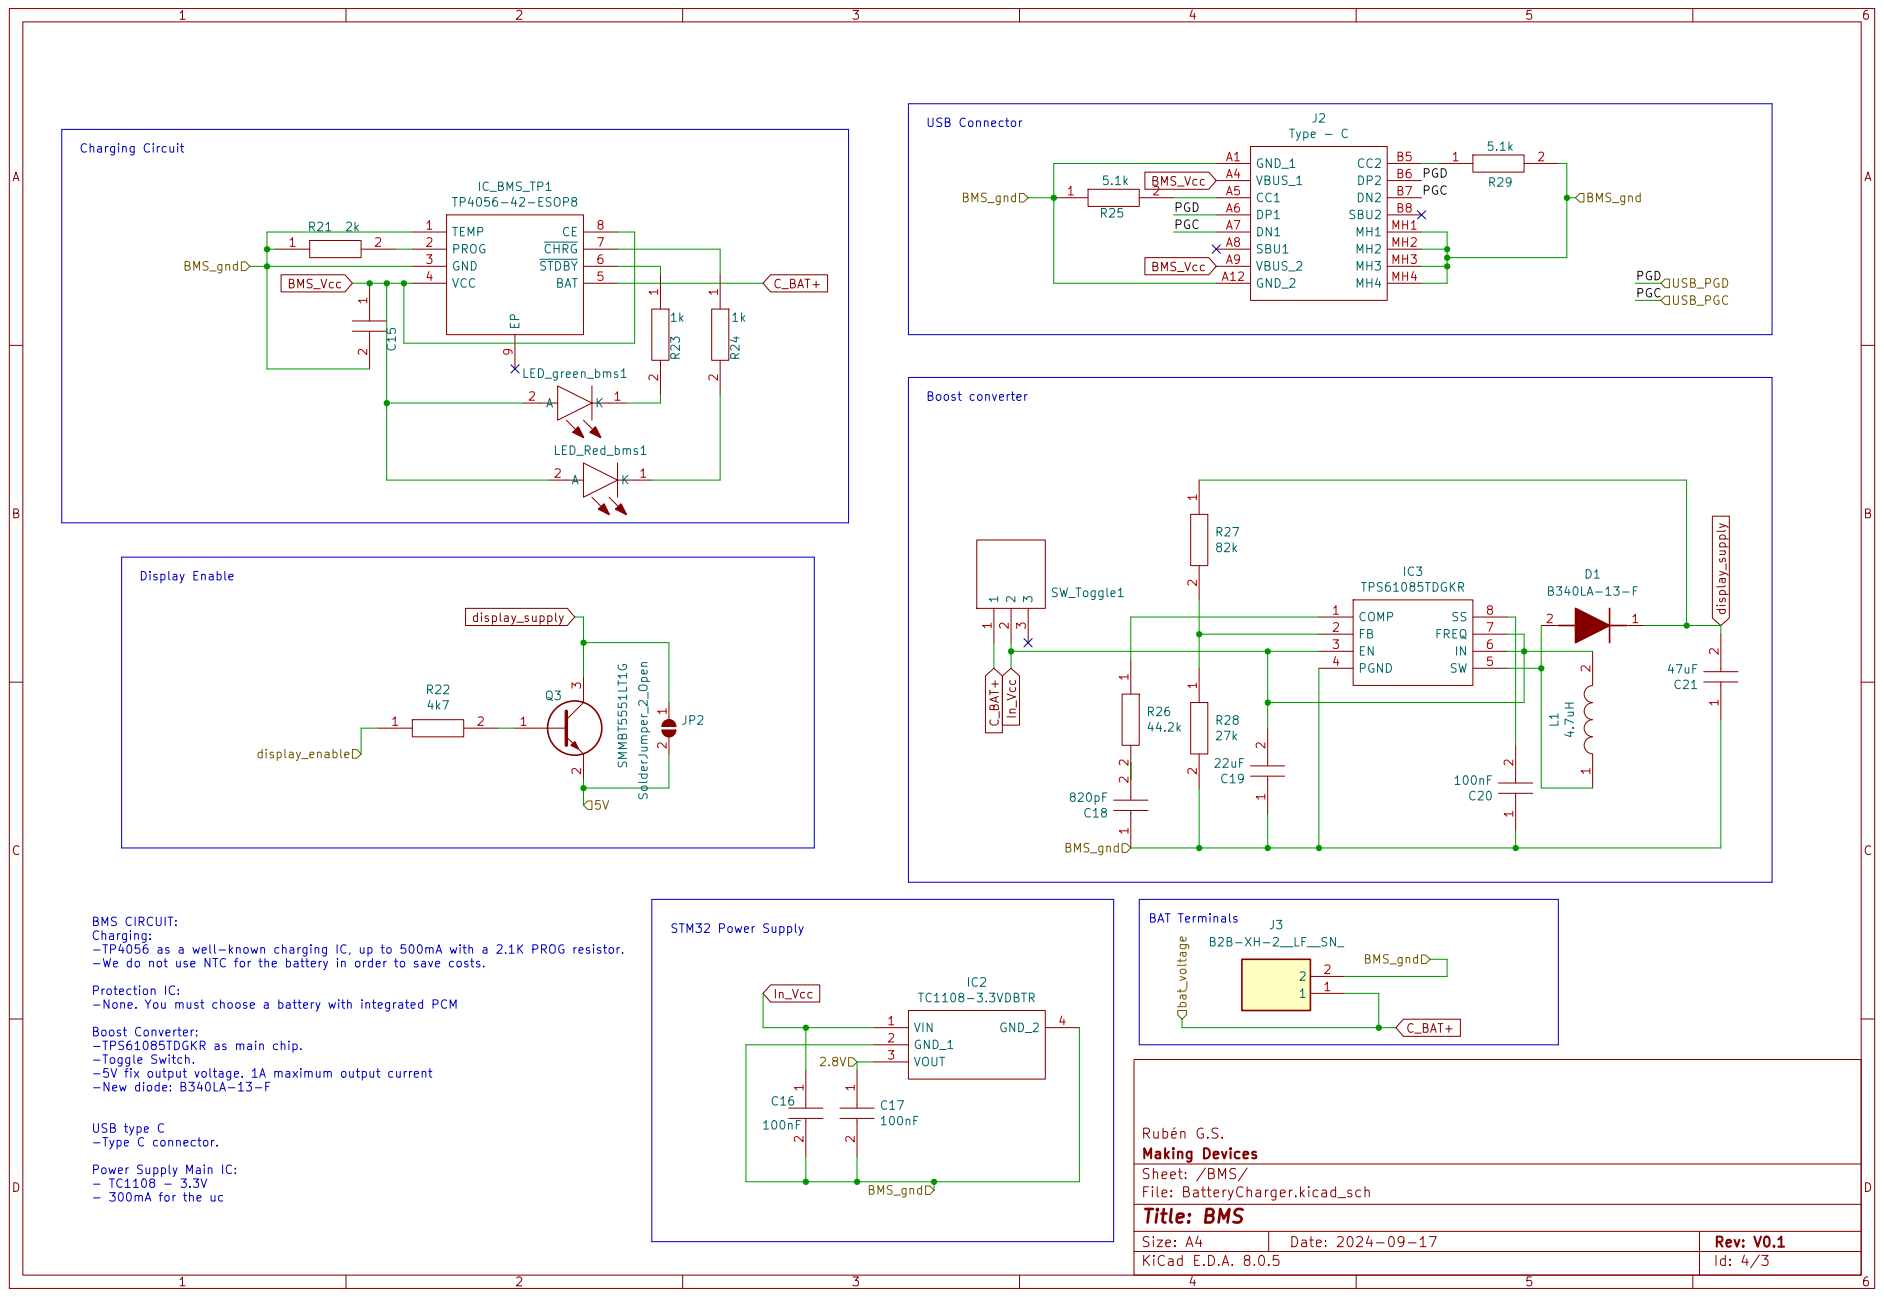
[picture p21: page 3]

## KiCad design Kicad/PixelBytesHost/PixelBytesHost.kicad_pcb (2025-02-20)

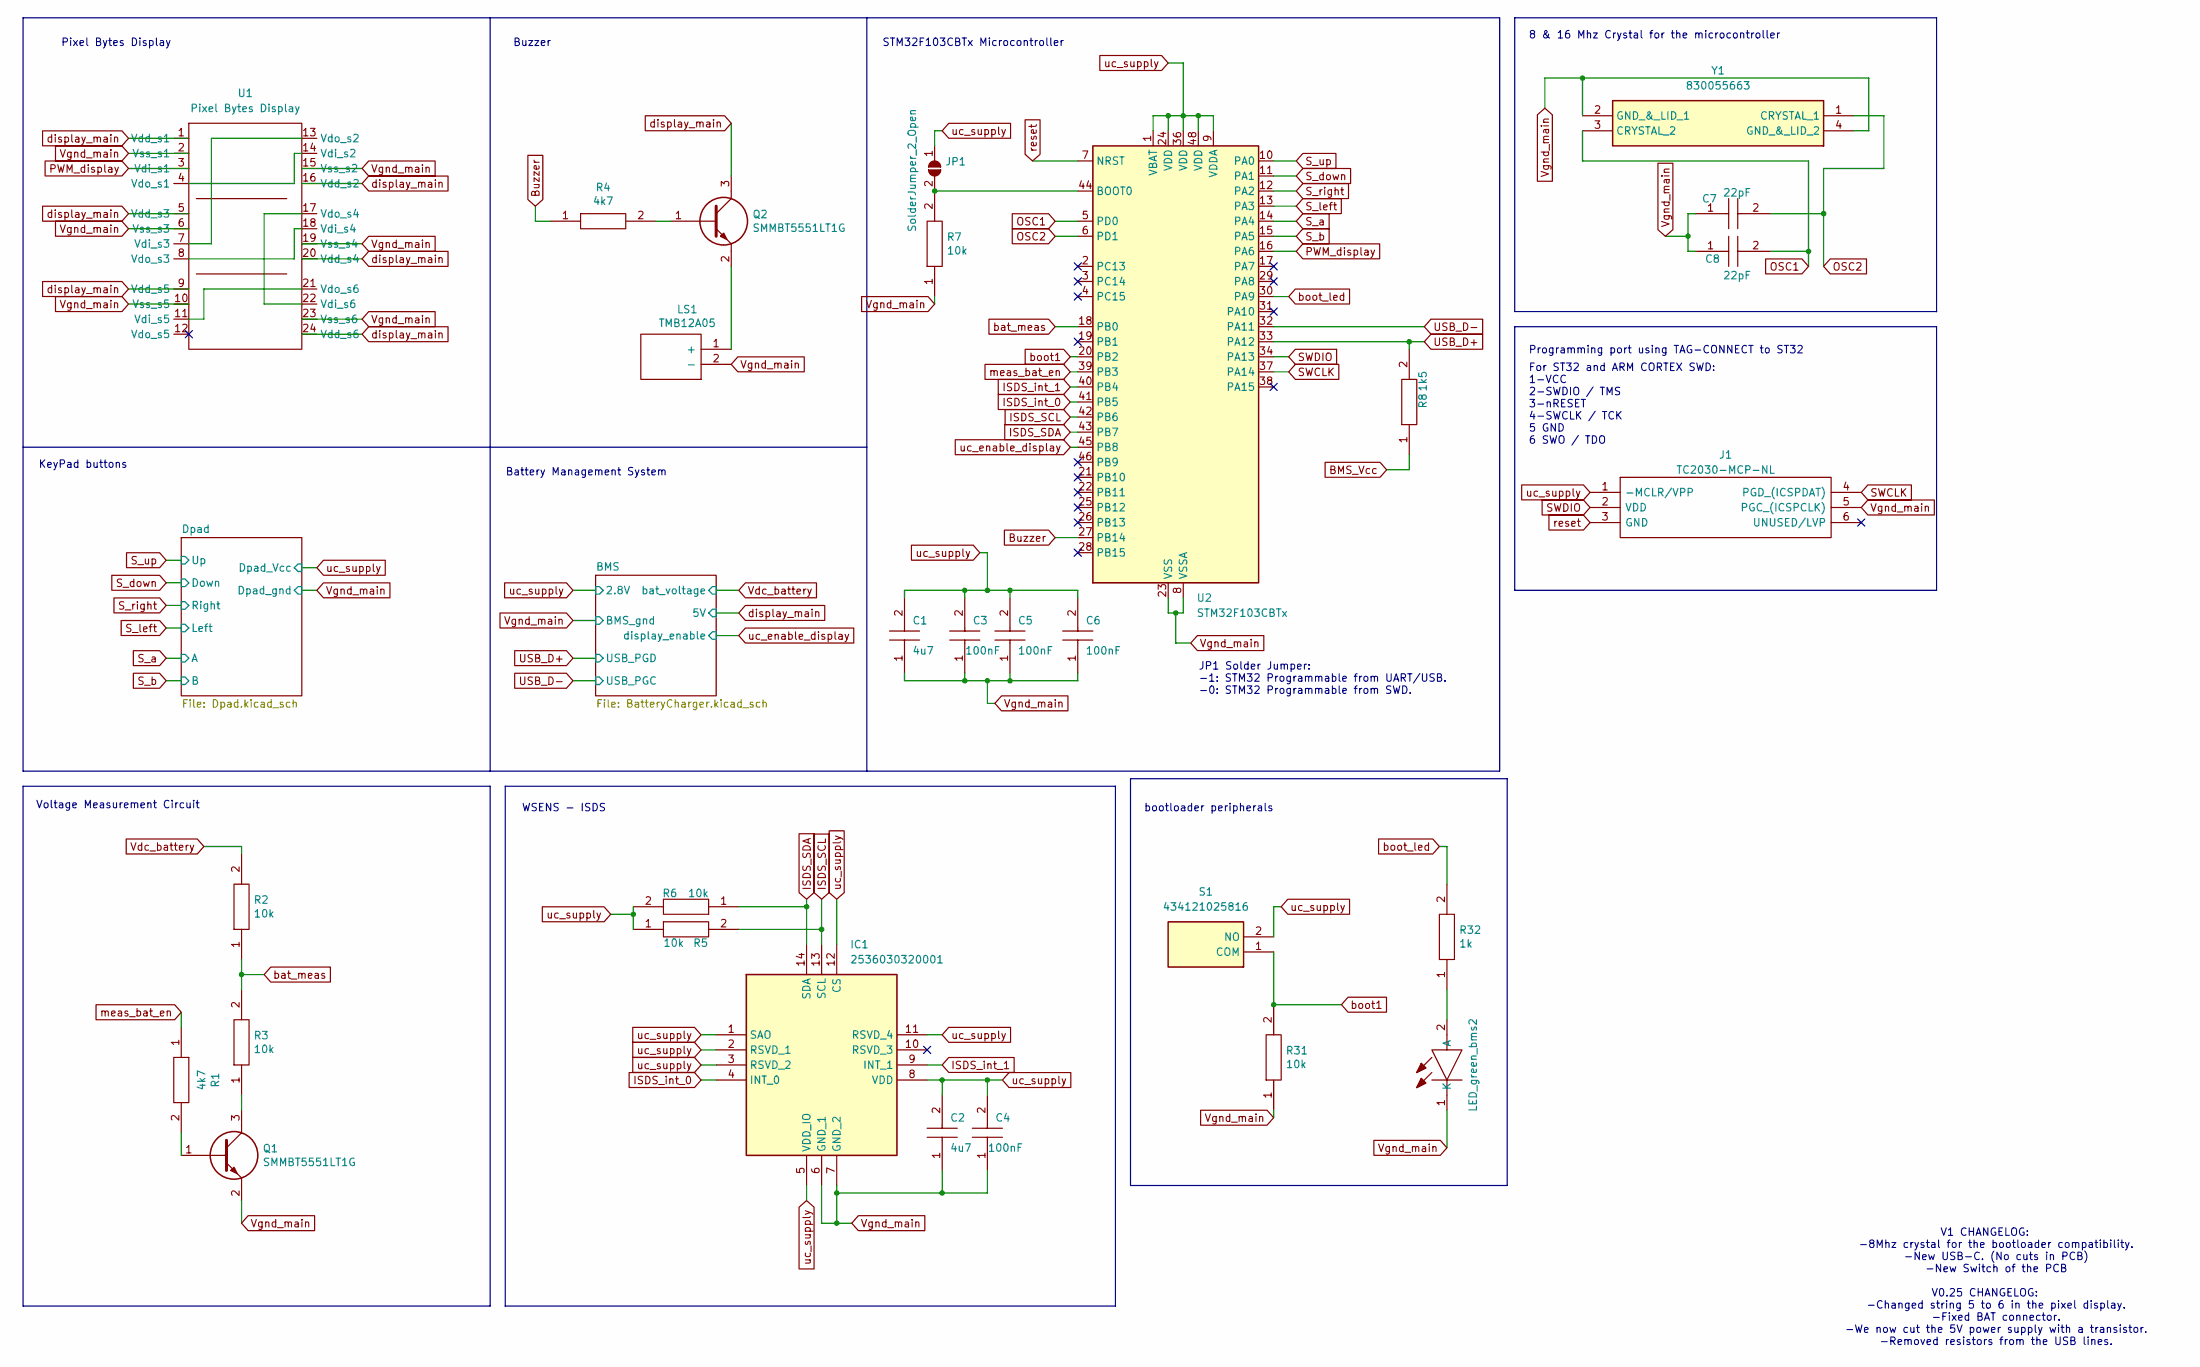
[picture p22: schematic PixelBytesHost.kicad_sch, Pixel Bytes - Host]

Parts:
C1, C2: 4u7; CAPC2012X140N; Manufacturer_Part_Number C0805C475M8RACTU
C3, C4, C5, C6: 100nF; CAPC2012X140N; Manufacturer_Part_Number C0805C475M8RACTU
C7, C8: 22pF; C_0805_2012Metric; Manufacturer_Part_Number GCG21BR71H154KA01K
IC1: 2536030320001; Mouser Part Number 710-2536030320001
J1: TC2030-MCP-NL; Manufacturer_Part_Number TC2030-MCP-NL
JP1: SolderJumper_2_Open; SolderJumper-2_P1.3mm_Open_RoundedPad1.0x1.5mm
LED_green_bms2: LTST-C171GKT; LEDC2012X90N; Manufacturer_Part_Number LTST-C171GKT
LS1: TMB12A05; Manufacturer_Part_Number TMB12A05
Q1, Q2: SMMBT5551LT1G; SOT96P237X111-3N; Manufacturer_Part_Number SMMBT5551LT1G
R1, R4: 4k7; RESC2012X65N; Manufacturer_Part_Number KTR10EZPF4220
R2, R3, R5, R6, R7, R31: 10k; R_0805_2012Metric; Manufacturer_Part_Number ERJP6WF1303V
R8: 1k5; R_0805_2012Metric; Manufacturer_Part_Number ERJP6WF1303V
R32: 1k; R_0805_2012Metric; Manufacturer_Part_Number ERJP6WF1303V
S1: 434121025816; 434121050816; Manufacturer_Part_Number 434121025816; Mouser Part Number 710-434121025816
U1: Pixel Bytes Display; pixelbytesdisplay
U2: STM32F103CBTx; LQFP-48_7x7mm_P0.5mm
Y1: 830055663; Mouser Part Number 710-830055663

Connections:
BMS_Vcc: R8.1; also elsewhere on the board
Buzzer: R4.1, U2.27 (PB14)
ISDS_SCL: IC1.13 (SCL), R5.2, U2.42 (PB6)
ISDS_SDA: IC1.14 (SDA), R6.1, U2.43 (PB7)
ISDS_int_0: IC1.4 (INT_0), U2.41 (PB5)
ISDS_int_1: IC1.9 (INT_1), U2.40 (PB4)
unnamed: JP1.2 (B), R7.2, U2.44 (BOOT0)
unnamed: LED_green_bms2.2 (A), R32.1
unnamed: LS1.1 (+), Q2.2
unnamed: Q1.1, R1.2
unnamed: Q1.3, R3.1
unnamed: Q2.1, R4.2
unnamed: U1.4 (Vdo_s1), U1.14 (Vdi_s2)
unnamed: U1.7 (Vdi_s3), U1.13 (Vdo_s2)
unnamed: U1.8 (Vdo_s3), U1.18 (Vdi_s4)
unnamed: U1.11 (Vdi_s5), U1.21 (Vdo_s6)
unnamed: U1.17 (Vdo_s4), U1.22 (Vdi_s6)
OSC1: C8.2, U2.5 (PD0), Y1.3 (CRYSTAL_2)
OSC2: C7.2, U2.6 (PD1), Y1.1 (CRYSTAL_1)
PWM_display: U1.3 (Vdi_s1), U2.16 (PA6)
SWCLK: J1.4 (PGD_(ICSPDAT)), U2.37 (PA14)
SWDIO: J1.2 (VDD), U2.34 (PA13)
S_a: U2.14 (PA4); also elsewhere on the board
S_b: U2.15 (PA5); also elsewhere on the board
S_down: U2.11 (PA1); also elsewhere on the board
S_left: U2.13 (PA3); also elsewhere on the board
S_right: U2.12 (PA2); also elsewhere on the board
S_up: U2.10 (PA0); also elsewhere on the board
USB_D+: R8.2, U2.33 (PA12); also elsewhere on the board
USB_D-: U2.32 (PA11); also elsewhere on the board
Vdc_battery: R2.2; also elsewhere on the board
Vgnd_main: C1.1, C2.1, C3.1, C4.1, C5.1, C6.1, C7.1, C8.1, IC1.6 (GND_1), IC1.7 (GND_2), J1.5 (PGC_(ICSPCLK)), LED_green_bms2.1 (K), LS1.2 (-), Q1.2, R7.1, R31.1, U1.2 (Vss_s1), U1.6 (Vss_s3), U1.10 (Vss_s5), U1.15 (Vss_s2), U1.19 (Vss_s4), U1.23 (Vss_s6), U2.8 (VSSA), U2.23 (VSS), U2.35 (VSS), U2.47 (VSS), Y1.2 (GND_&_LID_1), Y1.4 (GND_&_LID_2); also elsewhere on the board
bat_meas: R2.1, R3.2, U2.18 (PB0)
boot1: R31.2, S1.1 (COM), U2.20 (PB2)
boot_led: R32.2, U2.30 (PA9)
meas_bat_en: R1.1, U2.39 (PB3)
reset: J1.3 (GND), U2.7 (NRST)
uc_enable_display: U2.45 (PB8); also elsewhere on the board
uc_supply: C1.2, C2.2, C3.2, C4.2, C5.2, C6.2, IC1.1 (SAO), IC1.2 (RSVD_1), IC1.3 (RSVD_2), IC1.5 (VDD_IO), IC1.8 (VDD), IC1.11 (RSVD_4), IC1.12 (CS), J1.1 (-MCLR/VPP), JP1.1 (A), R5.1, R6.2, S1.2 (NO), U2.1 (VBAT), U2.9 (VDDA), U2.24 (VDD), U2.36 (VDD), U2.48 (VDD); also elsewhere on the board

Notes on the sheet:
KeyPad buttons
Battery Management System
JP1 Solder Jumper: -1: STM32 Programmable from UART/USB. -0: STM32 Programmable from SWD.
WSENS - ISDS
V1 CHANGELOG: -8Mhz crystal for the bootloader compatibility. -New USB-C. (No cuts in PCB) -New Switch of the PCB V0.25 CHANGELOG: -Changed string 5 to 6 in the pixel display. -Fixed BAT connector. -We now cut the 5V power supply with a transistor. -Removed resistors from the USB lines.
Programming port using TAG-CONNECT to ST32
8 & 16 Mhz Crystal for the microcontroller
Pixel Bytes Display
bootloader peripherals
Buzzer
For ST32 and ARM CORTEX SWD: 1-VCC 2-SWDIO / TMS 3-nRESET 4-SWCLK / TCK 5 GND 6 SWO / TDO
STM32F103CBTx Microcontroller
Voltage Measurement Circuit

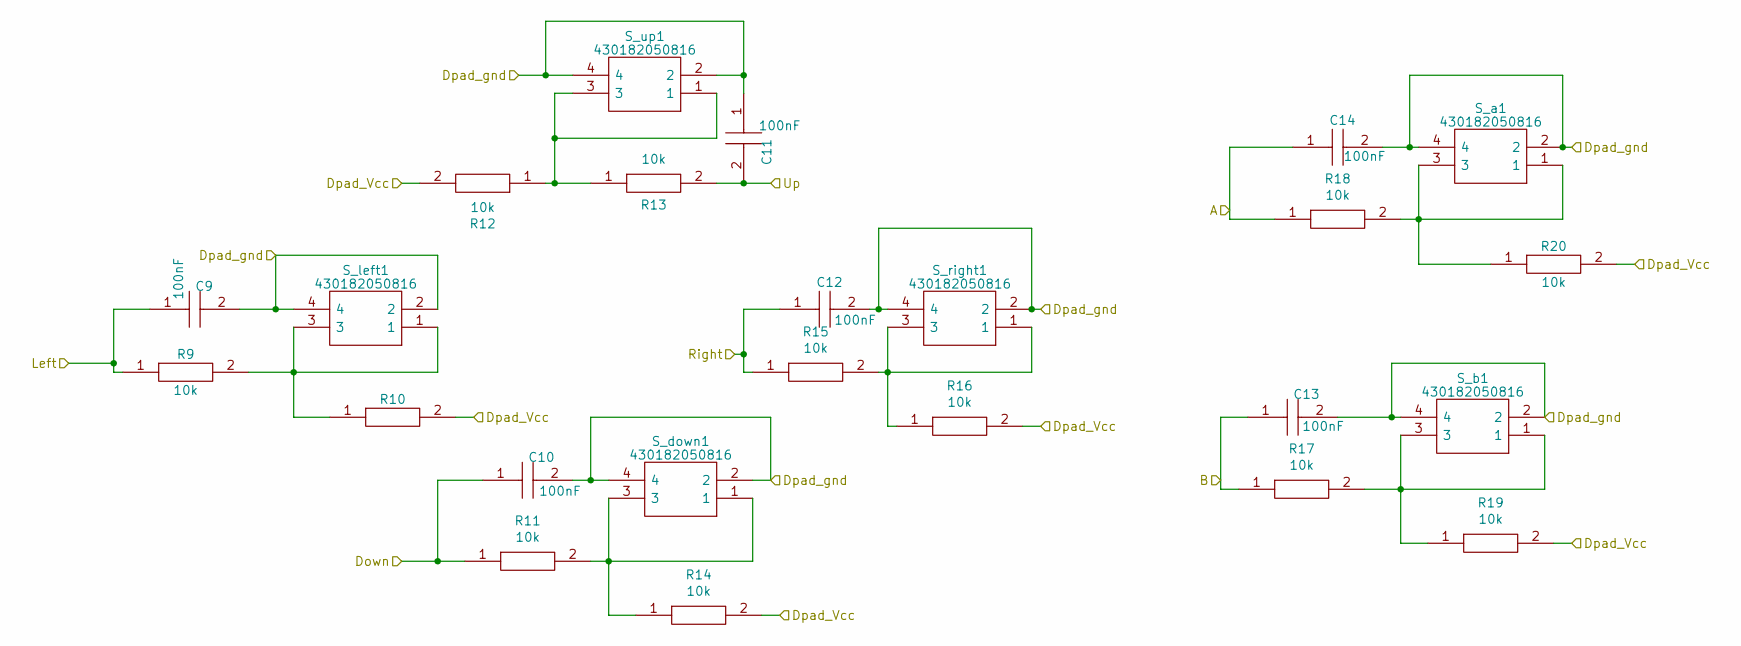
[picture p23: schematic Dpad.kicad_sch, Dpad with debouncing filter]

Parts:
C9, C10, C11, C12, C13, C14: 100nF; CAPC2012X140N; Manufacturer_Part_Number GCG21BR71H154KA01K
R9, R10, R11, R12, R13, R14, R15, R16, R17, R18, R19, R20: 10k; R_0805_2012Metric; Manufacturer_Part_Number KTR10EZPF4220
S_a1: 430182050816; 430182070816; Mouser Part Number 710-430182050816
S_b1: 430182050816; 430182070816; Mouser Part Number 710-430182050816
S_down1: 430182050816; 430182070816; Mouser Part Number 710-430182050816
S_left1: 430182050816; 430182070816; Mouser Part Number 710-430182050816
S_right1: 430182050816; 430182070816; Mouser Part Number 710-430182050816
S_up1: 430182050816; 430182070816; Mouser Part Number 710-430182050816

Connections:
unnamed: R9.2, R10.1, S_left1.1, S_left1.3
unnamed: R11.2, R14.1, S_down1.1, S_down1.3
unnamed: R12.1, R13.1, S_up1.1, S_up1.3
unnamed: R15.2, R16.1, S_right1.1, S_right1.3
unnamed: R17.2, R19.1, S_b1.1, S_b1.3
unnamed: R18.2, R20.1, S_a1.1, S_a1.3
S_a: C14.1, R18.1; also elsewhere on the board
S_b: C13.1, R17.1; also elsewhere on the board
S_down: C10.1, R11.1; also elsewhere on the board
S_left: C9.1, R9.1; also elsewhere on the board
S_right: C12.1, R15.1; also elsewhere on the board
S_up: C11.2, R13.2; also elsewhere on the board
Vgnd_main: C9.2, C10.2, C11.1, C12.2, C13.2, C14.2, S_a1.2, S_a1.4, S_b1.2, S_b1.4, S_down1.2, S_down1.4, S_left1.2, S_left1.4, S_right1.2, S_right1.4, S_up1.2, S_up1.4; also elsewhere on the board
uc_supply: R10.2, R12.2, R14.2, R16.2, R19.2, R20.2; also elsewhere on the board

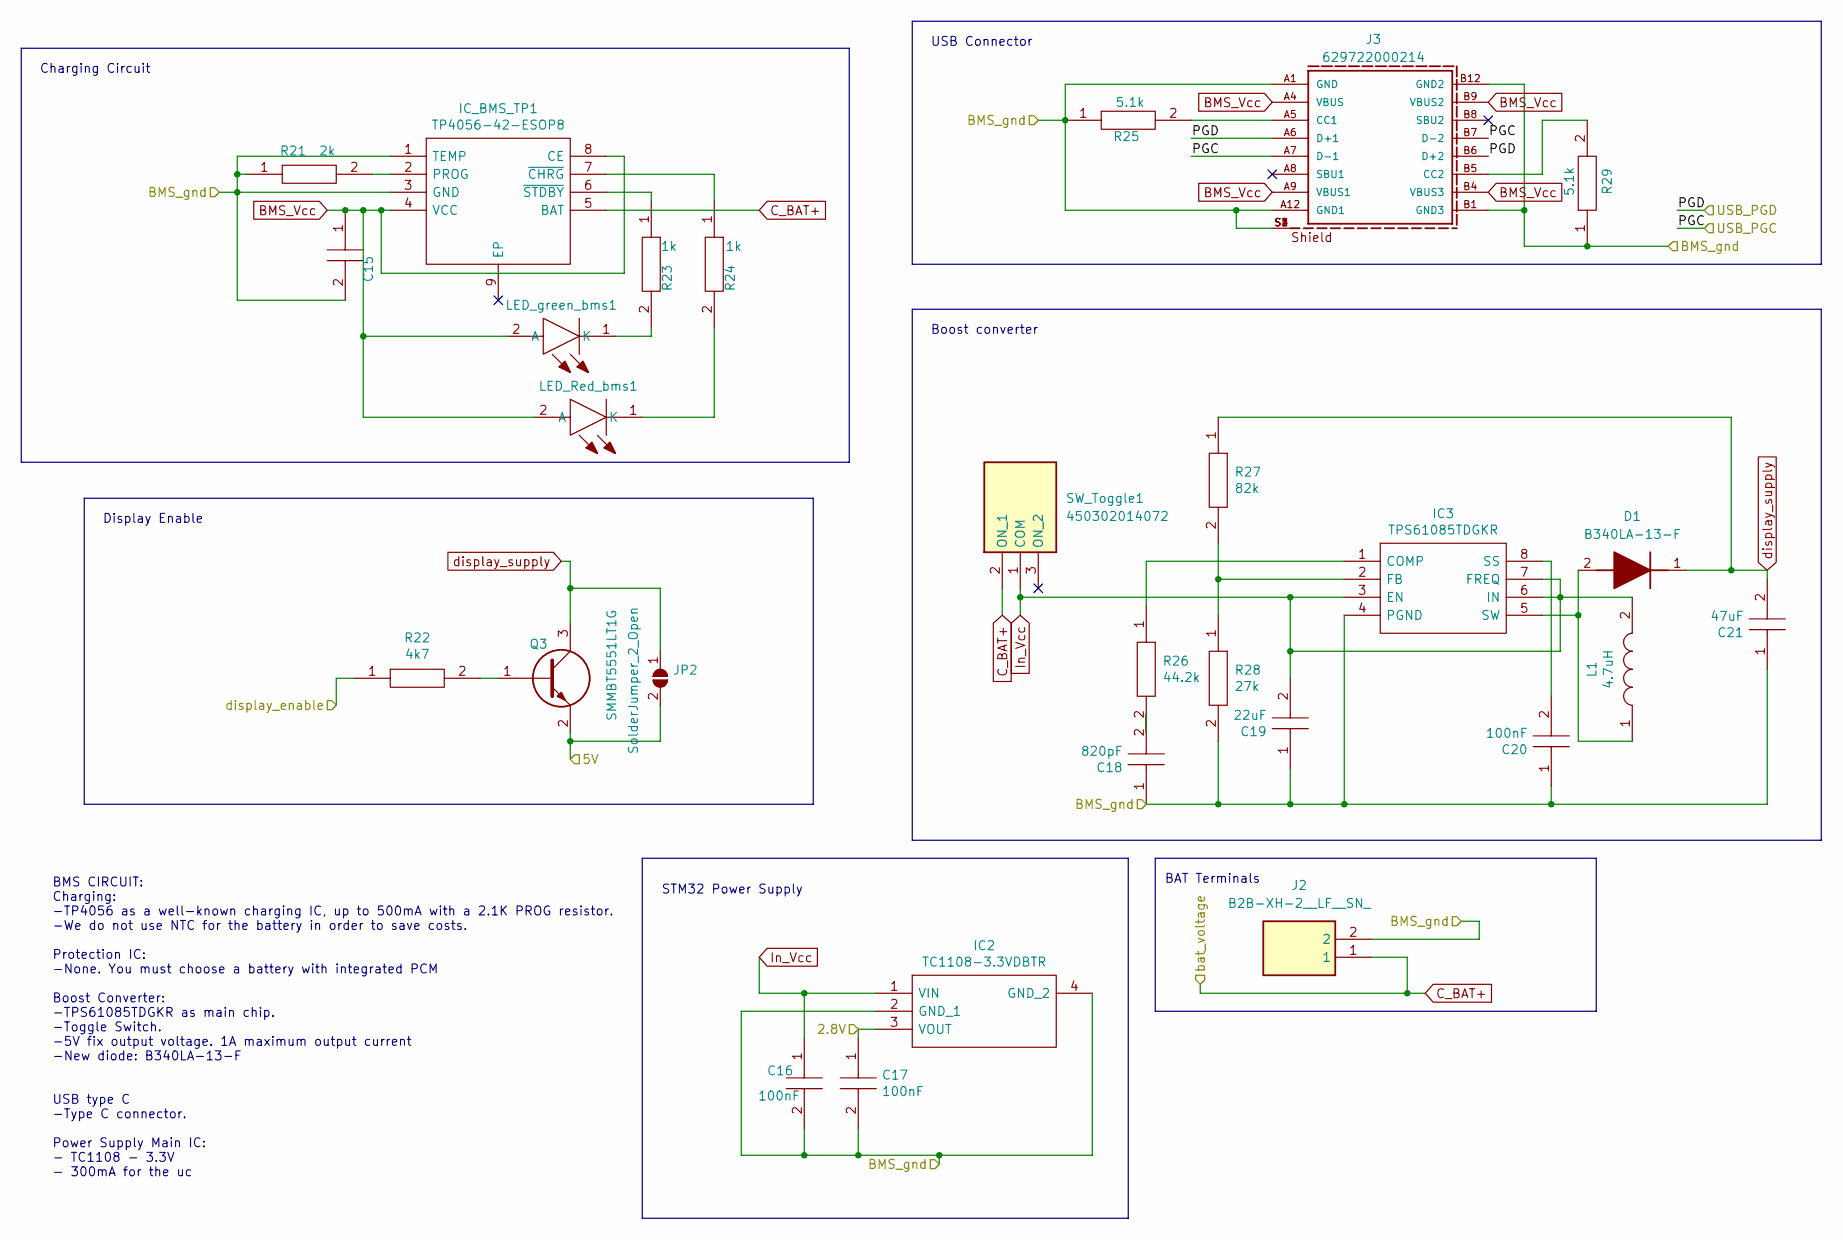
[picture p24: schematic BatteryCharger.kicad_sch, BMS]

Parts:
C15: 10uF; CAPC2012X145N; Manufacturer_Part_Number GCG21BR71H154KA01K
C16, C17, C20: 100nF; CAPC2012X140N; Manufacturer_Part_Number C0805C475M8RACTU
C18: 820pF; CAPC2012X140N; Manufacturer_Part_Number C0805C475M8RACTU
C19: 22uF; CAPC2012X140N; Manufacturer_Part_Number C0805C475M8RACTU
C21: 47uF; CAPC2012X140N; Manufacturer_Part_Number C0805C475M8RACTU
D1: B340LA-13-F; DIOM5226X240N; Mouser Part Number 621-B340LA-F
IC2: TC1108-3.3VDBTR; SOT230P700X180-4N; Manufacturer_Part_Number TC1108-3.3VDBTR
IC3: TPS61085TDGKR; SOP65P490X110-8N; Mouser Part Number 595-TPS61085TDGKR
IC_BMS_TP1: TP4056-42-ESOP8; SOIC127P600X175-9N; Manufacturer_Part_Number TP4056-42-ESOP8
J2: B2B-XH-2__LF__SN_; B2BXH2LFSN; Manufacturer_Part_Number B2B-XH-2 (LF)(SN)
J3: 629722000214; PART-NUMBER 629722000214
JP2: SolderJumper_2_Open; SolderJumper-2_P1.3mm_Open_RoundedPad1.0x1.5mm
L1: 4.7uH; SRN6045_1; Mouser Part Number 652-SRN6045-4R7Y
LED_Red_bms1: LTST-C171GKT; LEDC2012X90N; Manufacturer_Part_Number LTST-C171GKT
LED_green_bms1: LTST-C171GKT; LEDC2012X90N; Manufacturer_Part_Number LTST-C171GKT
Q3: SMMBT5551LT1G; SOT96P237X111-3N; Manufacturer_Part_Number SMMBT5551LT1G
R21: 2k; RESC2012X65N; Manufacturer_Part_Number KTR10EZPF4220
R22: 4k7; RESC2012X65N; Manufacturer_Part_Number KTR10EZPF4220
R23, R24: 1k; RESC2012X65N; Manufacturer_Part_Number KTR10EZPF4220
R25, R29: 5.1k; RESC2012X65N; Manufacturer_Part_Number KTR10EZPF4220
R26: 44.2k; RESC2012X75N; Manufacturer_Part_Number ERJP6WF1303V
R27: 82k; RESC2012X75N; Manufacturer_Part_Number ERJP6WF1303V
R28: 27k; RESC2012X75N; Manufacturer_Part_Number ERJP6WF1303V
SW_Toggle1: 450302014072; Mouser Part Number 710-450302014072

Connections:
BMS_Vcc: C15.1, IC_BMS_TP1.4 (VCC), IC_BMS_TP1.8 (CE), J3.A4 (VBUS), J3.A9 (VBUS1), J3.B4 (VBUS3), J3.B9 (VBUS2), LED_Red_bms1.2 (A), LED_green_bms1.2 (A); also elsewhere on the board
In_Vcc: C16.1, C19.2, IC2.1 (VIN), IC3.3 (EN), IC3.6 (IN), IC3.7 (FREQ), L1.2, SW_Toggle1.1 (COM)
unnamed: C18.2, R26.2
unnamed: D1.2 (A), IC3.5 (SW), L1.1
unnamed: IC3.1 (COMP), R26.1
unnamed: IC3.2 (FB), R27.2, R28.1
unnamed: C20.2, IC3.8 (SS)
unnamed: IC_BMS_TP1.2 (PROG), R21.2
unnamed: IC_BMS_TP1.7 (~CHRG), R24.1
unnamed: IC_BMS_TP1.6 (~STDBY), R23.1
unnamed: J3.A5 (CC1), R25.2
unnamed: J3.B5 (CC2), R29.2
unnamed: LED_Red_bms1.1 (K), R24.2
unnamed: LED_green_bms1.1 (K), R23.2
unnamed 25: Q3.1 (B), R22.2; also elsewhere on the board
USB_D+: J3.A6 (D+1), J3.B6 (D+2); also elsewhere on the board
USB_D-: J3.A7 (D-1), J3.B7 (D-2); also elsewhere on the board
Vdc_battery: IC_BMS_TP1.5 (BAT), J2.1, SW_Toggle1.2 (ON_1); also elsewhere on the board
Vgnd_main: C15.2, C16.2, C17.2, C18.1, C19.1, C20.1, C21.1, IC2.2 (GND_1), IC2.4 (GND_2), IC3.4 (PGND), IC_BMS_TP1.1 (TEMP), IC_BMS_TP1.3 (GND), J2.2, J3.A1 (GND), J3.A12 (GND1), J3.B1 (GND3), J3.B12 (GND2), J3.S1, J3.S2, J3.S3, J3.S4, R21.1, R25.1, R28.2, R29.1; also elsewhere on the board
uc_enable_display: R22.1; also elsewhere on the board
uc_supply: C17.1, IC2.3 (VOUT); also elsewhere on the board

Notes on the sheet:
Boost converter
BMS CIRCUIT: Charging: -TP4056 as a well-known charging IC, up to 500mA with a 2.1K PROG resistor. -We do not use NTC for the battery in order to save costs. Protection IC: -None. You must choose a battery with integrated PCM Boost Converter: -TPS61085TDGKR as main chip. -Toggle Switch. -5V fix out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
Display Enable
USB Connector
STM32 Power Supply
BAT Terminals
Charging Circuit

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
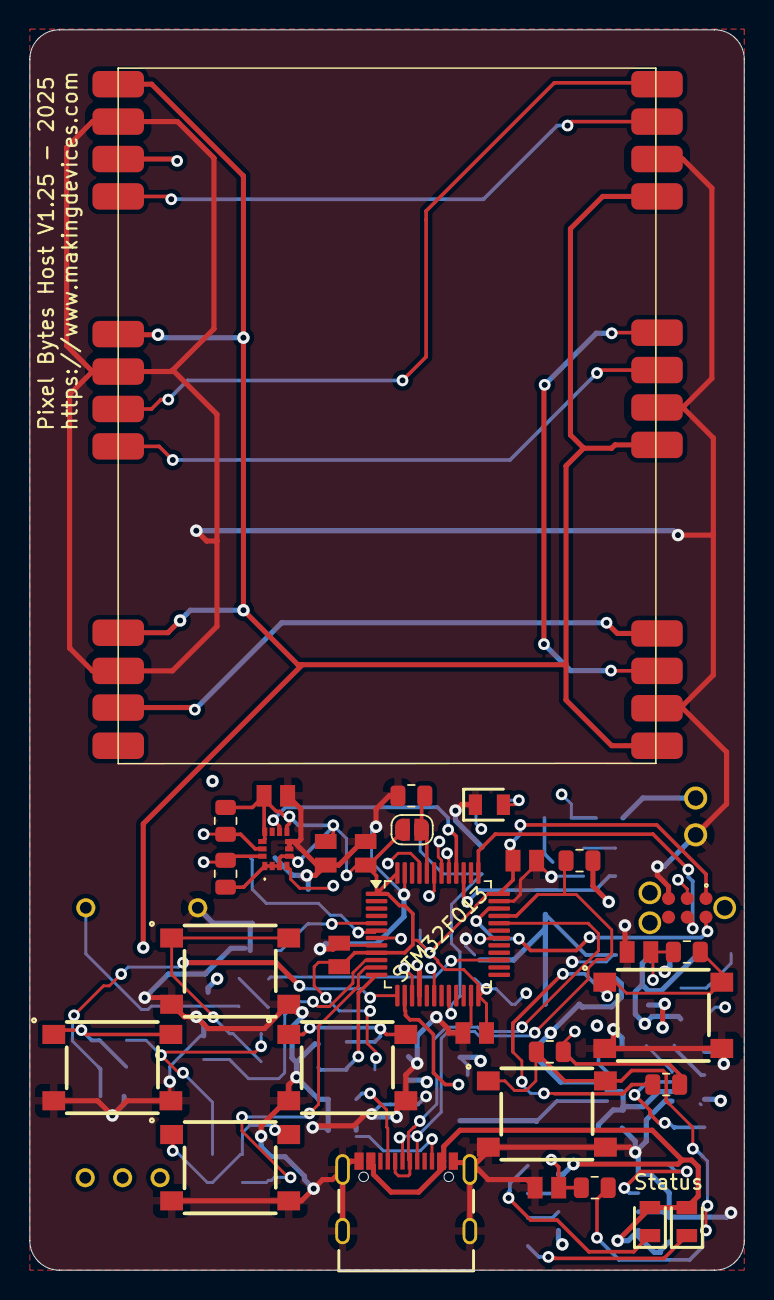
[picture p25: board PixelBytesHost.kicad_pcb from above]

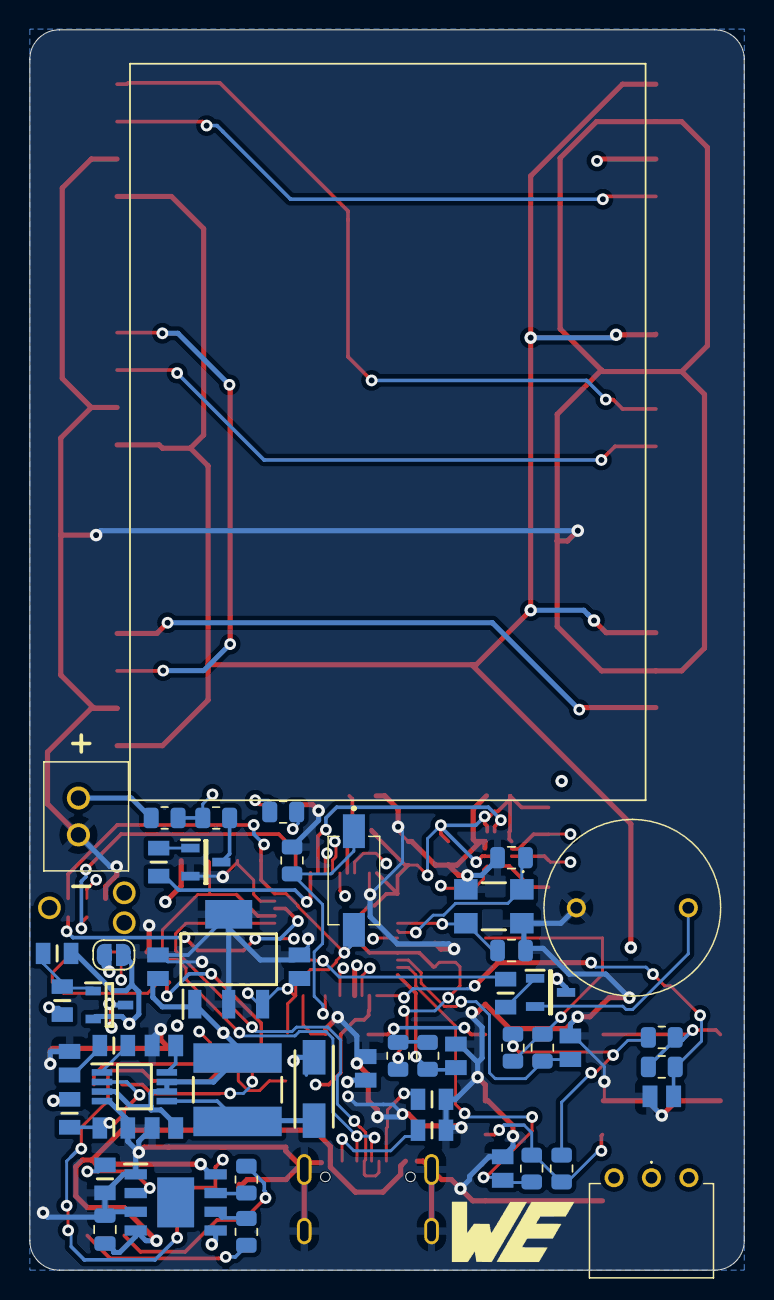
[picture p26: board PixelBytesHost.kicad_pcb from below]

Board: 4 copper layers, 48.5 x 84.2 mm, 82 parts (51 on the bottom side), 61 nets.

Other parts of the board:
R30: 3k3; RESC2012X65N

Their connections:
unnamed 25: R30.1; also elsewhere on the board

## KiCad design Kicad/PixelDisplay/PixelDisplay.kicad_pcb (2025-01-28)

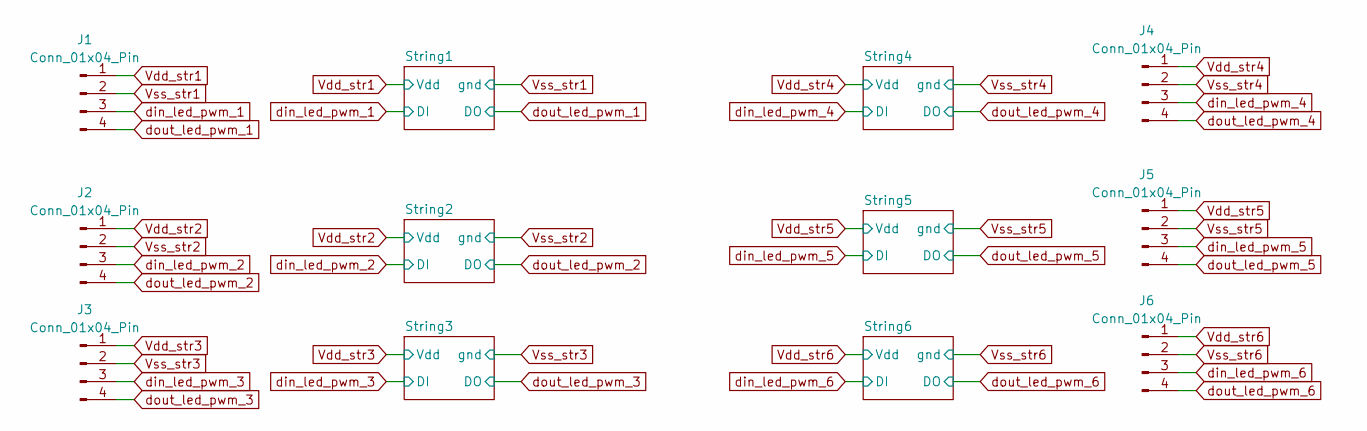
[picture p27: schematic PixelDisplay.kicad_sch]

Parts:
J1, J2, J3, J4, J5, J6: Conn_01x04_Pin; castellated_4x2.54mm

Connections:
Vdd_str1: J1.1; also elsewhere on the board
Vdd_str2: J2.1; also elsewhere on the board
Vdd_str3: J3.1; also elsewhere on the board
Vdd_str4: J4.1; also elsewhere on the board
Vdd_str5: J5.1; also elsewhere on the board
Vdd_str6: J6.1; also elsewhere on the board
Vss_str1: J1.2; also elsewhere on the board
Vss_str2: J2.2; also elsewhere on the board
Vss_str3: J3.2; also elsewhere on the board
Vss_str4: J4.2; also elsewhere on the board
Vss_str5: J5.2; also elsewhere on the board
Vss_str6: J6.2; also elsewhere on the board
din_led_pwm_1: J1.3; also elsewhere on the board
din_led_pwm_2: J2.3; also elsewhere on the board
din_led_pwm_3: J3.3; also elsewhere on the board
din_led_pwm_4: J4.3; also elsewhere on the board
din_led_pwm_5: J5.3; also elsewhere on the board
din_led_pwm_6: J6.3; also elsewhere on the board
dout_led_pwm_1: J1.4; also elsewhere on the board
dout_led_pwm_2: J2.4; also elsewhere on the board
dout_led_pwm_3: J3.4; also elsewhere on the board
dout_led_pwm_4: J4.4; also elsewhere on the board
dout_led_pwm_5: J5.4; also elsewhere on the board
dout_led_pwm_6: J6.4; also elsewhere on the board

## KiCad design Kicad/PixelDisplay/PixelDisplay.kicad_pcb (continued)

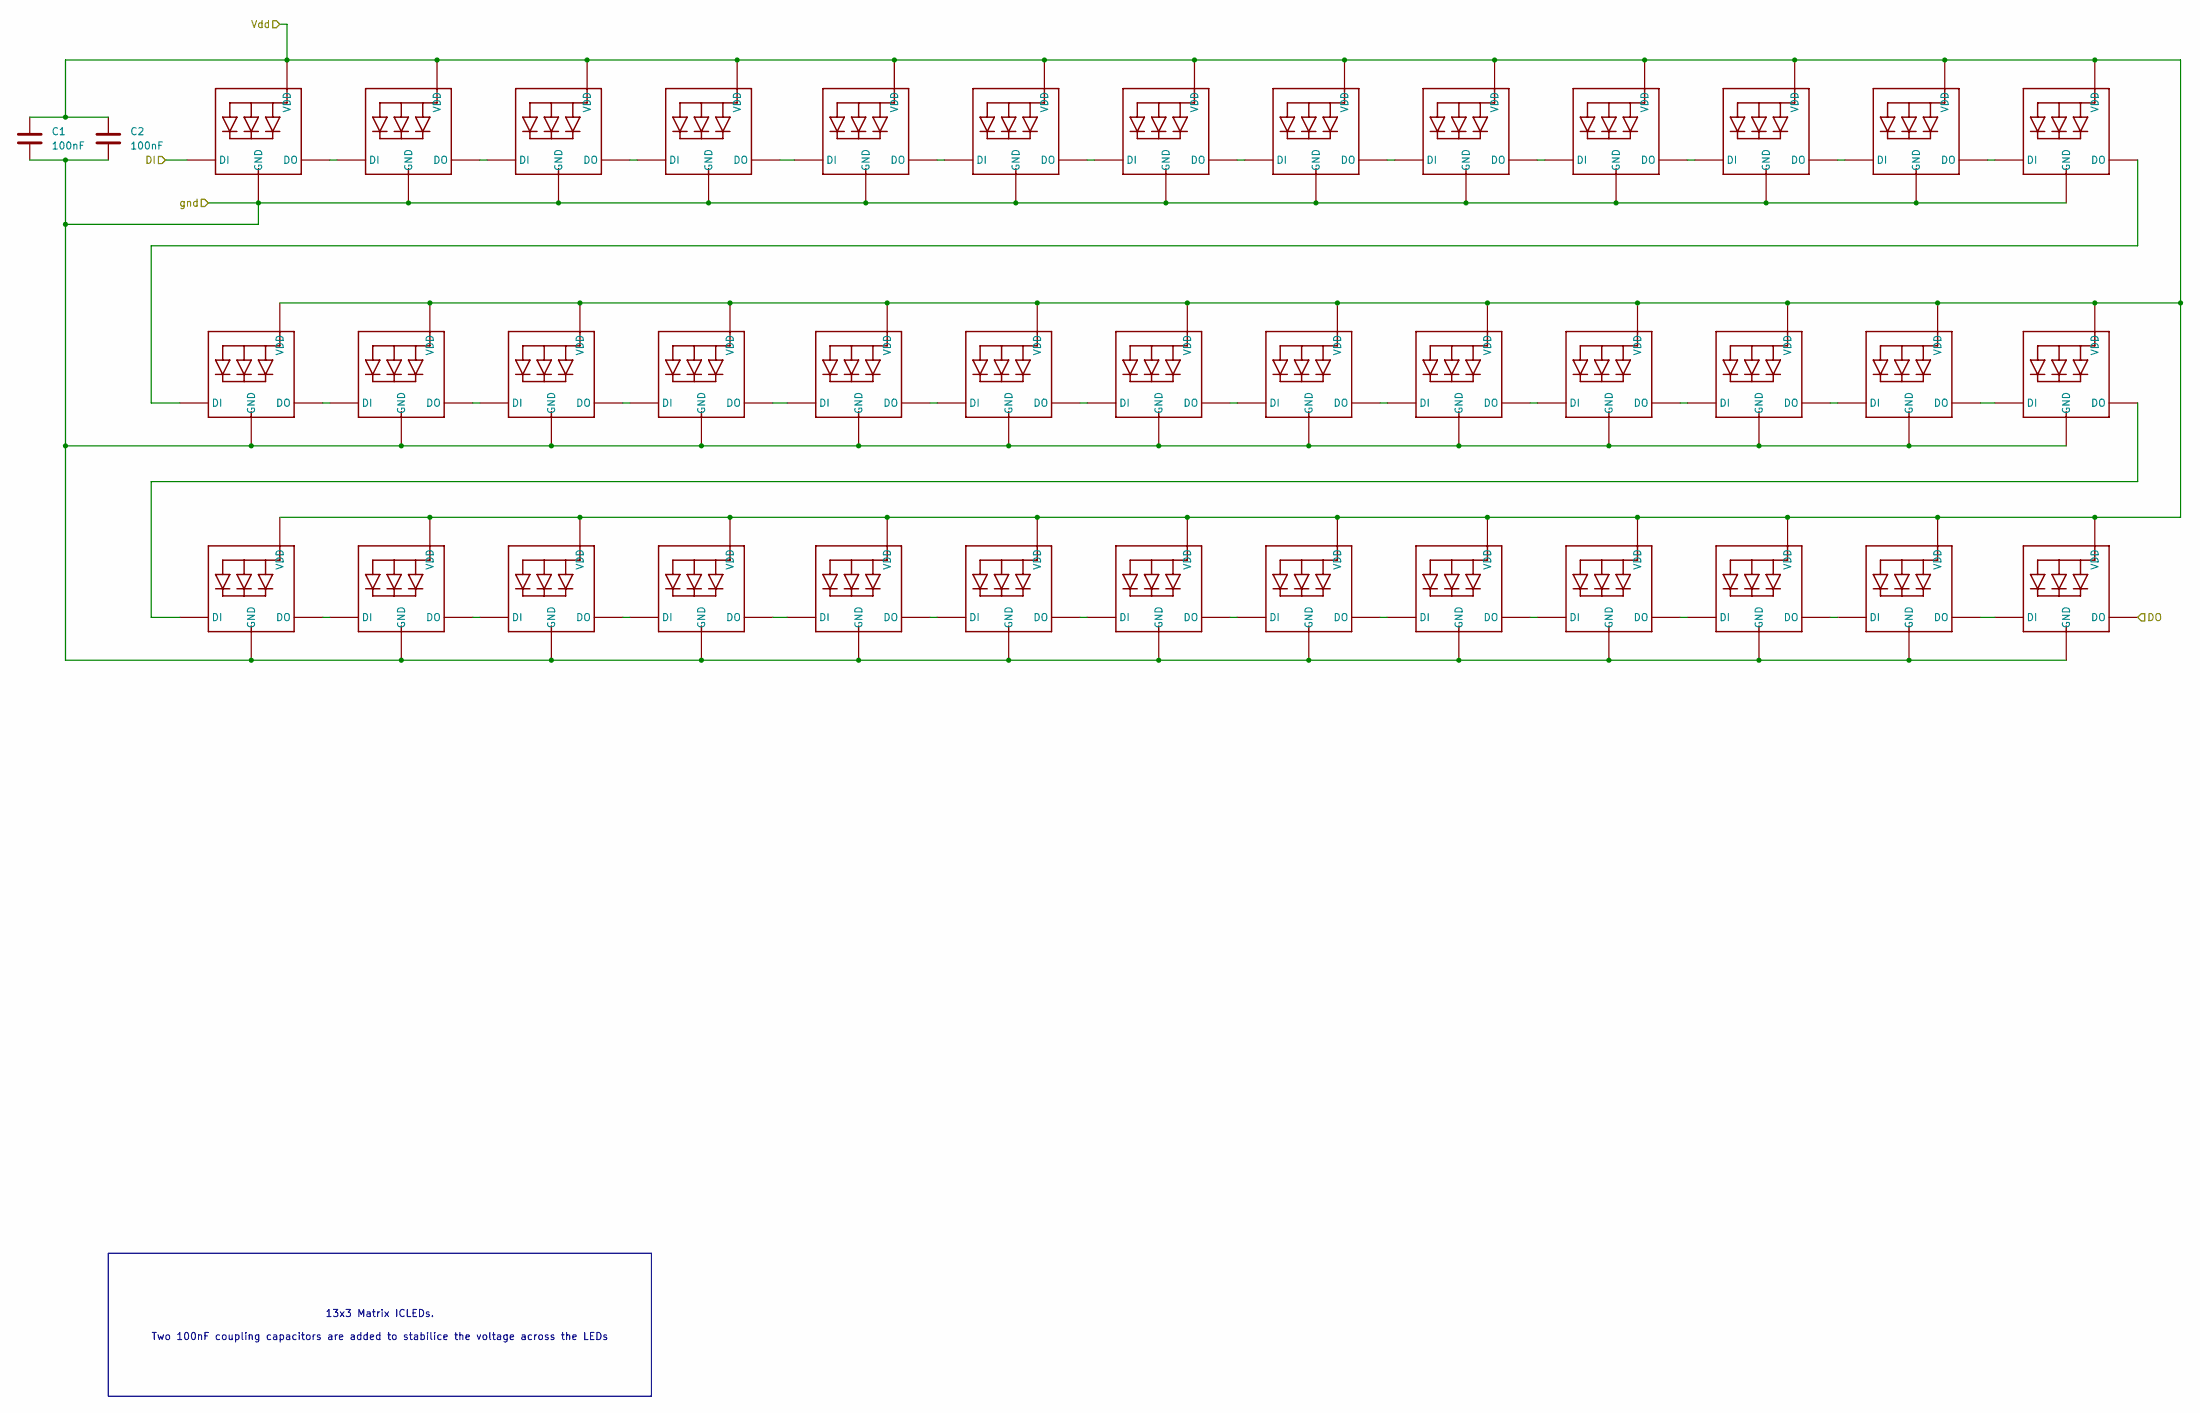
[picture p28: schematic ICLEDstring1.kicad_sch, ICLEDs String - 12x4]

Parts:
C1, C2: 100nF; C_0805_2012Metric
ICled1, ICled2, ICled3, ICled4, ICled5, ICled6, ICled7, ICled8, ICled9, ICled10, ICled11, ICled12, ICled13, ICled14, ICled15, ICled16, ICled17, ICled18, ICled19, ICled20, ICled21, ICled22, ICled23, ICled24, ICled25, ICled26, ICled27, ICled28, ICled29, ICled30, ICled31, ICled32, ICled33, ICled34, ICled35, ICled36, ICled37, ICled38, ICled39: 1312020030000

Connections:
unnamed: ICled1.3-DIN (DI), ICled37.1-DOUT (DO)
unnamed: ICled1.1-DOUT (DO), ICled4.3-DIN (DI)
unnamed: ICled2.3-DIN (DI), ICled38.1-DOUT (DO)
unnamed: ICled2.1-DOUT (DO), ICled5.3-DIN (DI)
unnamed: ICled3.1-DOUT (DO), ICled6.3-DIN (DI)
unnamed: ICled4.1-DOUT (DO), ICled7.3-DIN (DI)
unnamed: ICled5.1-DOUT (DO), ICled8.3-DIN (DI)
unnamed: ICled6.1-DOUT (DO), ICled9.3-DIN (DI)
unnamed: ICled7.1-DOUT (DO), ICled10.3-DIN (DI)
unnamed: ICled10.1-DOUT (DO), ICled13.3-DIN (DI)
unnamed: ICled8.1-DOUT (DO), ICled11.3-DIN (DI)
unnamed: ICled11.1-DOUT (DO), ICled14.3-DIN (DI)
unnamed: ICled9.1-DOUT (DO), ICled12.3-DIN (DI)
unnamed: ICled12.1-DOUT (DO), ICled15.3-DIN (DI)
unnamed: ICled13.1-DOUT (DO), ICled16.3-DIN (DI)
unnamed: ICled14.1-DOUT (DO), ICled17.3-DIN (DI)
unnamed: ICled15.1-DOUT (DO), ICled18.3-DIN (DI)
unnamed: ICled16.1-DOUT (DO), ICled19.3-DIN (DI)
unnamed: ICled17.1-DOUT (DO), ICled20.3-DIN (DI)
unnamed: ICled18.1-DOUT (DO), ICled21.3-DIN (DI)
unnamed: ICled19.1-DOUT (DO), ICled22.3-DIN (DI)
unnamed: ICled20.1-DOUT (DO), ICled23.3-DIN (DI)
unnamed: ICled21.1-DOUT (DO), ICled24.3-DIN (DI)
unnamed: ICled22.1-DOUT (DO), ICled25.3-DIN (DI)
unnamed: ICled23.1-DOUT (DO), ICled26.3-DIN (DI)
unnamed: ICled24.1-DOUT (DO), ICled27.3-DIN (DI)
unnamed: ICled25.1-DOUT (DO), ICled28.3-DIN (DI)
unnamed: ICled26.1-DOUT (DO), ICled29.3-DIN (DI)
unnamed: ICled27.1-DOUT (DO), ICled30.3-DIN (DI)
unnamed: ICled28.1-DOUT (DO), ICled31.3-DIN (DI)
unnamed: ICled29.1-DOUT (DO), ICled32.3-DIN (DI)
unnamed: ICled30.1-DOUT (DO), ICled33.3-DIN (DI)
unnamed: ICled31.1-DOUT (DO), ICled34.3-DIN (DI)
unnamed: ICled32.1-DOUT (DO), ICled35.3-DIN (DI)
unnamed: ICled33.1-DOUT (DO), ICled36.3-DIN (DI)
unnamed: ICled34.1-DOUT (DO), ICled38.3-DIN (DI)
unnamed: ICled35.1-DOUT (DO), ICled39.3-DIN (DI)
unnamed: ICled36.1-DOUT (DO), ICled37.3-DIN (DI)
Vdd_str1: C1.1, C2.1, ICled1.2-VDD (VDD), ICled2.2-VDD (VDD), ICled3.2-VDD (VDD), ICled4.2-VDD (VDD), ICled5.2-VDD (VDD), ICled6.2-VDD (VDD), ICled7.2-VDD (VDD), ICled8.2-VDD (VDD), ICled9.2-VDD (VDD), ICled10.2-VDD (VDD), ICled11.2-VDD (VDD), ICled12.2-VDD (VDD), ICled13.2-VDD (VDD), ICled14.2-VDD (VDD), ICled15.2-VDD (VDD), ICled16.2-VDD (VDD), ICled17.2-VDD (VDD), ICled18.2-VDD (VDD), ICled19.2-VDD (VDD), ICled20.2-VDD (VDD), ICled21.2-VDD (VDD), ICled22.2-VDD (VDD), ICled23.2-VDD (VDD), ICled24.2-VDD (VDD), ICled25.2-VDD (VDD), ICled26.2-VDD (VDD), ICled27.2-VDD (VDD), ICled28.2-VDD (VDD), ICled29.2-VDD (VDD), ICled30.2-VDD (VDD), ICled31.2-VDD (VDD), ICled32.2-VDD (VDD), ICled33.2-VDD (VDD), ICled34.2-VDD (VDD), ICled35.2-VDD (VDD), ICled36.2-VDD (VDD), ICled37.2-VDD (VDD), ICled38.2-VDD (VDD), ICled39.2-VDD (VDD); also elsewhere on the board
Vss_str1: C1.2, C2.2, ICled1.4-GND (GND), ICled2.4-GND (GND), ICled3.4-GND (GND), ICled4.4-GND (GND), ICled5.4-GND (GND), ICled6.4-GND (GND), ICled7.4-GND (GND), ICled8.4-GND (GND), ICled9.4-GND (GND), ICled10.4-GND (GND), ICled11.4-GND (GND), ICled12.4-GND (GND), ICled13.4-GND (GND), ICled14.4-GND (GND), ICled15.4-GND (GND), ICled16.4-GND (GND), ICled17.4-GND (GND), ICled18.4-GND (GND), ICled19.4-GND (GND), ICled20.4-GND (GND), ICled21.4-GND (GND), ICled22.4-GND (GND), ICled23.4-GND (GND), ICled24.4-GND (GND), ICled25.4-GND (GND), ICled26.4-GND (GND), ICled27.4-GND (GND), ICled28.4-GND (GND), ICled29.4-GND (GND), ICled30.4-GND (GND), ICled31.4-GND (GND), ICled32.4-GND (GND), ICled33.4-GND (GND), ICled34.4-GND (GND), ICled35.4-GND (GND), ICled36.4-GND (GND), ICled37.4-GND (GND), ICled38.4-GND (GND), ICled39.4-GND (GND); also elsewhere on the board
din_led_pwm_1: ICled3.3-DIN (DI); also elsewhere on the board
dout_led_pwm_1: ICled39.1-DOUT (DO); also elsewhere on the board

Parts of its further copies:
C3, C4, C5, C6, C7, C8, C9, C10, C11, C12: 100nF; C_0805_2012Metric
ICled40, ICled41, ICled42, ICled43, ICled44, ICled45, ICled46, ICled47, ICled48, ICled49, ICled50, ICled51, ICled52, ICled53, ICled54, ICled55, ICled56, ICled57, ICled58, ICled59, ICled60, ICled61, ICled62, ICled63, ICled64, ICled65, ICled66, ICled67, ICled68, ICled69, ICled70, ICled71, ICled72, ICled73, ICled74, ICled75, ICled76, ICled77, ICled78, ICled79, ICled80, ICled81, ICled82, ICled83, ICled84, ICled85, ICled86, ICled87, ICled88, ICled89, ICled90, ICled91, ICled92, ICled93, ICled94, ICled95, ICled96, ICled97, ICled98, ICled99, ICled100, ICled101, ICled102, ICled103, ICled104, ICled105, ICled106, ICled107, ICled108, ICled109, ICled110, ICled111, ICled112, ICled113, ICled114, ICled115, ICled116, ICled117, ICled118, ICled119, ICled120, ICled121, ICled122, ICled123, ICled124, ICled125, ICled126, ICled127, ICled128, ICled129, ICled130, ICled131, ICled132, ICled133, ICled134, ICled135, ICled136, ICled137, ICled138, ICled139, ICled140, ICled141, ICled142, ICled143, ICled144, ICled145, ICled146, ICled147, ICled148, ICled149, ICled150, ICled151, ICled152, ICled153, ICled154, ICled155, ICled156, ICled157, ICled158, ICled159, ICled160, ICled161, ICled162, ICled163, ICled164, ICled165, ICled166, ICled167, ICled168, ICled169, ICled170, ICled171, ICled172, ICled173, ICled174, ICled175, ICled176, ICled177, ICled178, ICled179, ICled180, ICled181, ICled182, ICled183, ICled184, ICled185, ICled186, ICled187, ICled188, ICled189, ICled190, ICled191, ICled192, ICled193, ICled194, ICled195, ICled196, ICled197, ICled198, ICled199, ICled200, ICled201, ICled202, ICled203, ICled204, ICled205, ICled206, ICled207, ICled208, ICled209, ICled210, ICled211, ICled212, ICled213, ICled214, ICled215, ICled216, ICled217, ICled218, ICled219, ICled220, ICled221, ICled222, ICled223, ICled224, ICled225, ICled226, ICled227, ICled228, ICled229, ICled230, ICled231, ICled232, ICled233, ICled234: 1312020030000

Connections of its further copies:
unnamed: ICled40.3-DIN (DI), ICled76.1-DOUT (DO)
unnamed: ICled40.1-DOUT (DO), ICled43.3-DIN (DI)
unnamed: ICled41.3-DIN (DI), ICled77.1-DOUT (DO)
unnamed: ICled41.1-DOUT (DO), ICled44.3-DIN (DI)
unnamed: ICled42.1-DOUT (DO), ICled45.3-DIN (DI)
unnamed: ICled43.1-DOUT (DO), ICled46.3-DIN (DI)
unnamed: ICled44.1-DOUT (DO), ICled47.3-DIN (DI)
unnamed: ICled45.1-DOUT (DO), ICled48.3-DIN (DI)
unnamed: ICled46.1-DOUT (DO), ICled49.3-DIN (DI)
unnamed: ICled47.1-DOUT (DO), ICled50.3-DIN (DI)
unnamed: ICled48.1-DOUT (DO), ICled51.3-DIN (DI)
unnamed: ICled49.1-DOUT (DO), ICled52.3-DIN (DI)
unnamed: ICled50.1-DOUT (DO), ICled53.3-DIN (DI)
unnamed: ICled51.1-DOUT (DO), ICled54.3-DIN (DI)
unnamed: ICled52.1-DOUT (DO), ICled55.3-DIN (DI)
unnamed: ICled53.1-DOUT (DO), ICled56.3-DIN (DI)
unnamed: ICled54.1-DOUT (DO), ICled57.3-DIN (DI)
unnamed: ICled55.1-DOUT (DO), ICled58.3-DIN (DI)
unnamed: ICled56.1-DOUT (DO), ICled59.3-DIN (DI)
unnamed: ICled57.1-DOUT (DO), ICled60.3-DIN (DI)
unnamed: ICled58.1-DOUT (DO), ICled61.3-DIN (DI)
unnamed: ICled59.1-DOUT (DO), ICled62.3-DIN (DI)
unnamed: ICled60.1-DOUT (DO), ICled63.3-DIN (DI)
unnamed: ICled61.1-DOUT (DO), ICled64.3-DIN (DI)
unnamed: ICled62.1-DOUT (DO), ICled65.3-DIN (DI)
unnamed: ICled63.1-DOUT (DO), ICled66.3-DIN (DI)
unnamed: ICled64.1-DOUT (DO), ICled67.3-DIN (DI)
unnamed: ICled65.1-DOUT (DO), ICled68.3-DIN (DI)
unnamed: ICled66.1-DOUT (DO), ICled69.3-DIN (DI)
unnamed: ICled67.1-DOUT (DO), ICled70.3-DIN (DI)
unnamed: ICled68.1-DOUT (DO), ICled71.3-DIN (DI)
unnamed: ICled69.1-DOUT (DO), ICled72.3-DIN (DI)
unnamed: ICled70.1-DOUT (DO), ICled73.3-DIN (DI)
unnamed: ICled71.1-DOUT (DO), ICled74.3-DIN (DI)
unnamed: ICled72.1-DOUT (DO), ICled75.3-DIN (DI)
unnamed: ICled73.1-DOUT (DO), ICled77.3-DIN (DI)
unnamed: ICled74.1-DOUT (DO), ICled78.3-DIN (DI)
unnamed: ICled75.1-DOUT (DO), ICled76.3-DIN (DI)
unnamed: ICled79.1-DOUT (DO), ICled82.3-DIN (DI)
unnamed: ICled80.1-DOUT (DO), ICled83.3-DIN (DI)
unnamed: ICled81.1-DOUT (DO), ICled84.3-DIN (DI)
unnamed: ICled82.1-DOUT (DO), ICled85.3-DIN (DI)
unnamed: ICled83.1-DOUT (DO), ICled86.3-DIN (DI)
unnamed: ICled84.1-DOUT (DO), ICled87.3-DIN (DI)
unnamed: ICled85.1-DOUT (DO), ICled88.3-DIN (DI)
unnamed: ICled86.1-DOUT (DO), ICled89.3-DIN (DI)
unnamed: ICled87.1-DOUT (DO), ICled90.3-DIN (DI)
unnamed: ICled88.1-DOUT (DO), ICled91.3-DIN (DI)
unnamed: ICled89.1-DOUT (DO), ICled92.3-DIN (DI)
unnamed: ICled90.1-DOUT (DO), ICled93.3-DIN (DI)
unnamed: ICled91.1-DOUT (DO), ICled94.3-DIN (DI)
unnamed: ICled92.1-DOUT (DO), ICled95.3-DIN (DI)
unnamed: ICled93.1-DOUT (DO), ICled96.3-DIN (DI)
unnamed: ICled94.1-DOUT (DO), ICled97.3-DIN (DI)
unnamed: ICled95.1-DOUT (DO), ICled98.3-DIN (DI)
unnamed: ICled96.1-DOUT (DO), ICled99.3-DIN (DI)
unnamed: ICled97.1-DOUT (DO), ICled100.3-DIN (DI)
unnamed: ICled100.1-DOUT (DO), ICled103.3-DIN (DI)
unnamed: ICled98.1-DOUT (DO), ICled101.3-DIN (DI)
unnamed: ICled101.1-DOUT (DO), ICled104.3-DIN (DI)
unnamed: ICled99.1-DOUT (DO), ICled102.3-DIN (DI)
unnamed: ICled102.1-DOUT (DO), ICled105.3-DIN (DI)
unnamed: ICled103.1-DOUT (DO), ICled106.3-DIN (DI)
unnamed: ICled104.1-DOUT (DO), ICled107.3-DIN (DI)
unnamed: ICled105.1-DOUT (DO), ICled108.3-DIN (DI)
unnamed: ICled106.1-DOUT (DO), ICled109.3-DIN (DI)
unnamed: ICled107.1-DOUT (DO), ICled110.3-DIN (DI)
unnamed: ICled108.1-DOUT (DO), ICled111.3-DIN (DI)
unnamed: ICled109.1-DOUT (DO), ICled112.3-DIN (DI)
unnamed: ICled110.1-DOUT (DO), ICled113.3-DIN (DI)
unnamed: ICled111.1-DOUT (DO), ICled114.3-DIN (DI)
unnamed: ICled112.1-DOUT (DO), ICled116.3-DIN (DI)
unnamed: ICled113.1-DOUT (DO), ICled117.3-DIN (DI)
unnamed: ICled114.1-DOUT (DO), ICled115.3-DIN (DI)
unnamed: ICled79.3-DIN (DI), ICled115.1-DOUT (DO)
unnamed: ICled80.3-DIN (DI), ICled116.1-DOUT (DO)
unnamed: ICled118.3-DIN (DI), ICled154.1-DOUT (DO)
unnamed: ICled118.1-DOUT (DO), ICled121.3-DIN (DI)
unnamed: ICled119.3-DIN (DI), ICled155.1-DOUT (DO)
unnamed: ICled119.1-DOUT (DO), ICled122.3-DIN (DI)
unnamed: ICled120.1-DOUT (DO), ICled123.3-DIN (DI)
unnamed: ICled121.1-DOUT (DO), ICled124.3-DIN (DI)
unnamed: ICled122.1-DOUT (DO), ICled125.3-DIN (DI)
unnamed: ICled123.1-DOUT (DO), ICled126.3-DIN (DI)
unnamed: ICled124.1-DOUT (DO), ICled127.3-DIN (DI)
unnamed: ICled125.1-DOUT (DO), ICled128.3-DIN (DI)
unnamed: ICled126.1-DOUT (DO), ICled129.3-DIN (DI)
unnamed: ICled127.1-DOUT (DO), ICled130.3-DIN (DI)
unnamed: ICled128.1-DOUT (DO), ICled131.3-DIN (DI)
unnamed: ICled129.1-DOUT (DO), ICled132.3-DIN (DI)
unnamed: ICled130.1-DOUT (DO), ICled133.3-DIN (DI)
unnamed: ICled131.1-DOUT (DO), ICled134.3-DIN (DI)
unnamed: ICled132.1-DOUT (DO), ICled135.3-DIN (DI)
unnamed: ICled133.1-DOUT (DO), ICled136.3-DIN (DI)
unnamed: ICled134.1-DOUT (DO), ICled137.3-DIN (DI)
unnamed: ICled135.1-DOUT (DO), ICled138.3-DIN (DI)
unnamed: ICled136.1-DOUT (DO), ICled139.3-DIN (DI)
unnamed: ICled137.1-DOUT (DO), ICled140.3-DIN (DI)
unnamed: ICled138.1-DOUT (DO), ICled141.3-DIN (DI)
unnamed: ICled139.1-DOUT (DO), ICled142.3-DIN (DI)
unnamed: ICled140.1-DOUT (DO), ICled143.3-DIN (DI)
unnamed: ICled141.1-DOUT (DO), ICled144.3-DIN (DI)
unnamed: ICled142.1-DOUT (DO), ICled145.3-DIN (DI)
unnamed: ICled143.1-DOUT (DO), ICled146.3-DIN (DI)
unnamed: ICled144.1-DOUT (DO), ICled147.3-DIN (DI)
unnamed: ICled145.1-DOUT (DO), ICled148.3-DIN (DI)
unnamed: ICled146.1-DOUT (DO), ICled149.3-DIN (DI)
unnamed: ICled147.1-DOUT (DO), ICled150.3-DIN (DI)
unnamed: ICled148.1-DOUT (DO), ICled151.3-DIN (DI)
unnamed: ICled149.1-DOUT (DO), ICled152.3-DIN (DI)
unnamed: ICled150.1-DOUT (DO), ICled153.3-DIN (DI)
unnamed: ICled151.1-DOUT (DO), ICled155.3-DIN (DI)
unnamed: ICled152.1-DOUT (DO), ICled156.3-DIN (DI)
unnamed: ICled153.1-DOUT (DO), ICled154.3-DIN (DI)
unnamed: ICled157.3-DIN (DI), ICled193.1-DOUT (DO)
unnamed: ICled157.1-DOUT (DO), ICled160.3-DIN (DI)
unnamed: ICled158.3-DIN (DI), ICled194.1-DOUT (DO)
unnamed: ICled158.1-DOUT (DO), ICled161.3-DIN (DI)
unnamed: ICled159.1-DOUT (DO), ICled162.3-DIN (DI)
unnamed: ICled160.1-DOUT (DO), ICled163.3-DIN (DI)
unnamed: ICled161.1-DOUT (DO), ICled164.3-DIN (DI)
unnamed: ICled162.1-DOUT (DO), ICled165.3-DIN (DI)
unnamed: ICled163.1-DOUT (DO), ICled166.3-DIN (DI)
unnamed: ICled164.1-DOUT (DO), ICled167.3-DIN (DI)
unnamed: ICled165.1-DOUT (DO), ICled168.3-DIN (DI)
unnamed: ICled166.1-DOUT (DO), ICled169.3-DIN (DI)
unnamed: ICled167.1-DOUT (DO), ICled170.3-DIN (DI)
unnamed: ICled168.1-DOUT (DO), ICled171.3-DIN (DI)
unnamed: ICled169.1-DOUT (DO), ICled172.3-DIN (DI)
unnamed: ICled170.1-DOUT (DO), ICled173.3-DIN (DI)
unnamed: ICled171.1-DOUT (DO), ICled174.3-DIN (DI)
unnamed: ICled172.1-DOUT (DO), ICled175.3-DIN (DI)
unnamed: ICled173.1-DOUT (DO), ICled176.3-DIN (DI)
unnamed: ICled174.1-DOUT (DO), ICled177.3-DIN (DI)
unnamed: ICled175.1-DOUT (DO), ICled178.3-DIN (DI)
unnamed: ICled176.1-DOUT (DO), ICled179.3-DIN (DI)
unnamed: ICled177.1-DOUT (DO), ICled180.3-DIN (DI)
unnamed: ICled178.1-DOUT (DO), ICled181.3-DIN (DI)
unnamed: ICled179.1-DOUT (DO), ICled182.3-DIN (DI)
unnamed: ICled180.1-DOUT (DO), ICled183.3-DIN (DI)
unnamed: ICled181.1-DOUT (DO), ICled184.3-DIN (DI)
unnamed: ICled182.1-DOUT (DO), ICled185.3-DIN (DI)
unnamed: ICled183.1-DOUT (DO), ICled186.3-DIN (DI)
unnamed: ICled184.1-DOUT (DO), ICled187.3-DIN (DI)
unnamed: ICled185.1-DOUT (DO), ICled188.3-DIN (DI)
unnamed: ICled186.1-DOUT (DO), ICled189.3-DIN (DI)
unnamed: ICled187.1-DOUT (DO), ICled190.3-DIN (DI)
unnamed: ICled188.1-DOUT (DO), ICled191.3-DIN (DI)
unnamed: ICled189.1-DOUT (DO), ICled192.3-DIN (DI)
unnamed: ICled190.1-DOUT (DO), ICled194.3-DIN (DI)
unnamed: ICled191.1-DOUT (DO), ICled195.3-DIN (DI)
unnamed: ICled192.1-DOUT (DO), ICled193.3-DIN (DI)
unnamed: ICled196.3-DIN (DI), ICled232.1-DOUT (DO)
unnamed: ICled196.1-DOUT (DO), ICled199.3-DIN (DI)
unnamed: ICled197.3-DIN (DI), ICled233.1-DOUT (DO)
unnamed: ICled197.1-DOUT (DO), ICled200.3-DIN (DI)
unnamed: ICled198.1-DOUT (DO), ICled201.3-DIN (DI)
unnamed: ICled199.1-DOUT (DO), ICled202.3-DIN (DI)
unnamed: ICled200.1-DOUT (DO), ICled203.3-DIN (DI)
unnamed: ICled201.1-DOUT (DO), ICled204.3-DIN (DI)
unnamed: ICled202.1-DOUT (DO), ICled205.3-DIN (DI)
unnamed: ICled203.1-DOUT (DO), ICled206.3-DIN (DI)
unnamed: ICled204.1-DOUT (DO), ICled207.3-DIN (DI)
unnamed: ICled205.1-DOUT (DO), ICled208.3-DIN (DI)
unnamed: ICled206.1-DOUT (DO), ICled209.3-DIN (DI)
unnamed: ICled207.1-DOUT (DO), ICled210.3-DIN (DI)
unnamed: ICled208.1-DOUT (DO), ICled211.3-DIN (DI)
unnamed: ICled209.1-DOUT (DO), ICled212.3-DIN (DI)
unnamed: ICled210.1-DOUT (DO), ICled213.3-DIN (DI)
unnamed: ICled211.1-DOUT (DO), ICled214.3-DIN (DI)
unnamed: ICled212.1-DOUT (DO), ICled215.3-DIN (DI)
unnamed: ICled213.1-DOUT (DO), ICled216.3-DIN (DI)
unnamed: ICled214.1-DOUT (DO), ICled217.3-DIN (DI)
unnamed: ICled215.1-DOUT (DO), ICled218.3-DIN (DI)
unnamed: ICled216.1-DOUT (DO), ICled219.3-DIN (DI)
unnamed: ICled217.1-DOUT (DO), ICled220.3-DIN (DI)
unnamed: ICled218.1-DOUT (DO), ICled221.3-DIN (DI)
unnamed: ICled219.1-DOUT (DO), ICled222.3-DIN (DI)
unnamed: ICled220.1-DOUT (DO), ICled223.3-DIN (DI)
unnamed: ICled221.1-DOUT (DO), ICled224.3-DIN (DI)
unnamed: ICled222.1-DOUT (DO), ICled225.3-DIN (DI)
unnamed: ICled223.1-DOUT (DO), ICled226.3-DIN (DI)
unnamed: ICled224.1-DOUT (DO), ICled227.3-DIN (DI)
unnamed: ICled225.1-DOUT (DO), ICled228.3-DIN (DI)
unnamed: ICled226.1-DOUT (DO), ICled229.3-DIN (DI)
unnamed: ICled227.1-DOUT (DO), ICled230.3-DIN (DI)
unnamed: ICled228.1-DOUT (DO), ICled231.3-DIN (DI)
unnamed: ICled229.1-DOUT (DO), ICled233.3-DIN (DI)
unnamed: ICled230.1-DOUT (DO), ICled234.3-DIN (DI)
unnamed: ICled231.1-DOUT (DO), ICled232.3-DIN (DI)
Vdd_str2: C3.1, C4.1, ICled40.2-VDD (VDD), ICled41.2-VDD (VDD), ICled42.2-VDD (VDD), ICled43.2-VDD (VDD), ICled44.2-VDD (VDD), ICled45.2-VDD (VDD), ICled46.2-VDD (VDD), ICled47.2-VDD (VDD), ICled48.2-VDD (VDD), ICled49.2-VDD (VDD), ICled50.2-VDD (VDD), ICled51.2-VDD (VDD), ICled52.2-VDD (VDD), ICled53.2-VDD (VDD), ICled54.2-VDD (VDD), ICled55.2-VDD (VDD), ICled56.2-VDD (VDD), ICled57.2-VDD (VDD), ICled58.2-VDD (VDD), ICled59.2-VDD (VDD), ICled60.2-VDD (VDD), ICled61.2-VDD (VDD), ICled62.2-VDD (VDD), ICled63.2-VDD (VDD), ICled64.2-VDD (VDD), ICled65.2-VDD (VDD), ICled66.2-VDD (VDD), ICled67.2-VDD (VDD), ICled68.2-VDD (VDD), ICled69.2-VDD (VDD), ICled70.2-VDD (VDD), ICled71.2-VDD (VDD), ICled72.2-VDD (VDD), ICled73.2-VDD (VDD), ICled74.2-VDD (VDD), ICled75.2-VDD (VDD), ICled76.2-VDD (VDD), ICled77.2-VDD (VDD), ICled78.2-VDD (VDD); also elsewhere on the board
Vdd_str3: C5.1, C6.1, ICled79.2-VDD (VDD), ICled80.2-VDD (VDD), ICled81.2-VDD (VDD), ICled82.2-VDD (VDD), ICled83.2-VDD (VDD), ICled84.2-VDD (VDD), ICled85.2-VDD (VDD), ICled86.2-VDD (VDD), ICled87.2-VDD (VDD), ICled88.2-VDD (VDD), ICled89.2-VDD (VDD), ICled90.2-VDD (VDD), ICled91.2-VDD (VDD), ICled92.2-VDD (VDD), ICled93.2-VDD (VDD), ICled94.2-VDD (VDD), ICled95.2-VDD (VDD), ICled96.2-VDD (VDD), ICled97.2-VDD (VDD), ICled98.2-VDD (VDD), ICled99.2-VDD (VDD), ICled100.2-VDD (VDD), ICled101.2-VDD (VDD), ICled102.2-VDD (VDD), ICled103.2-VDD (VDD), ICled104.2-VDD (VDD), ICled105.2-VDD (VDD), ICled106.2-VDD (VDD), ICled107.2-VDD (VDD), ICled108.2-VDD (VDD), ICled109.2-VDD (VDD), ICled110.2-VDD (VDD), ICled111.2-VDD (VDD), ICled112.2-VDD (VDD), ICled113.2-VDD (VDD), ICled114.2-VDD (VDD), ICled115.2-VDD (VDD), ICled116.2-VDD (VDD), ICled117.2-VDD (VDD); also elsewhere on the board
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

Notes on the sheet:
13x3 Matrix ICLEDs. Two 100nF coupling capacitors are added to stabilice the voltage across the LEDs

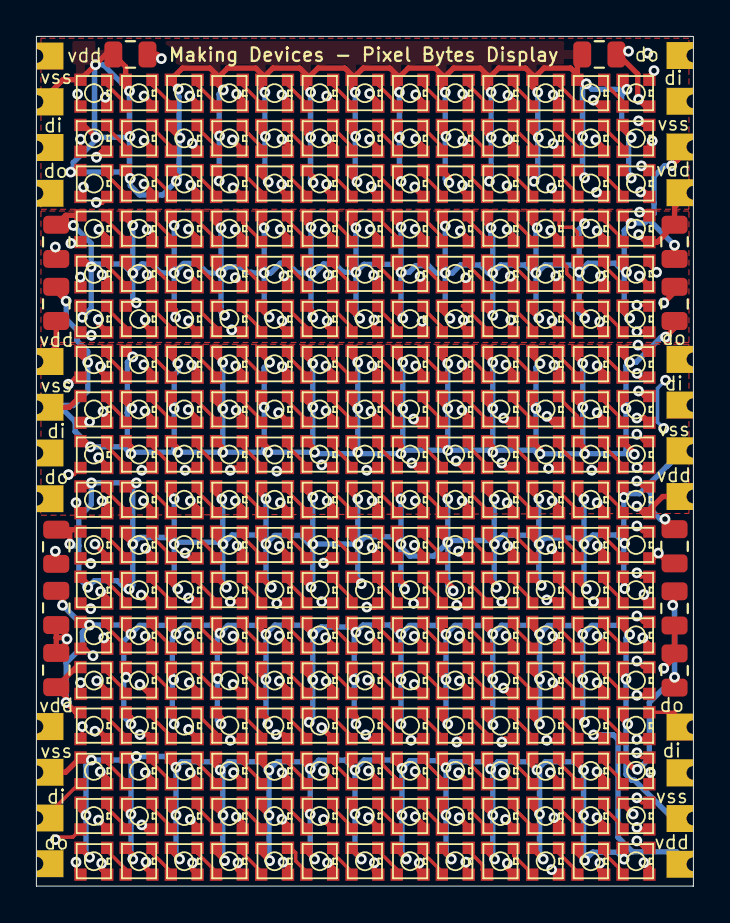
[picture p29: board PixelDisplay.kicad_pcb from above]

Board: 4 copper layers, 36.5 x 47.2 mm, 252 parts (0 on the bottom side), 252 nets.

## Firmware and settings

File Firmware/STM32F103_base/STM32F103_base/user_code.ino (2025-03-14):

void setup()
{
  //Serial.begin(9600);
  pixels.begin(); // INITIALIZE NeoPixel strip object (REQUIRED)
    // initialize PINs
  pinMode(PA0, INPUT);
  pinMode(PA1, INPUT);
  pinMode(PA2, INPUT);
  pinMode(PA3, INPUT);
  pinMode(PA4, INPUT);
  pinMode(PA5, INPUT);
  pinMode(PB8, OUTPUT); //Screen activation
  pinMode(PB2, OUTPUT);
  digitalWrite(PB2, HIGH);
  digitalWrite(PB8, LOW);
  delay(100);

  // Interval in microsecs
  if (ITimer.attachInterruptInterval(HW_TIMER_INTERVAL_MS * 1000, TimerHandler))
  {
    
  }

  // Just to demonstrate, don't use too many ISR Timers if not absolutely necessary
  // You can use up to 16 timer for each ISR_Timer
  ISR_Timer.setInterval(TIMER_INTERVAL_0_50mS,  TimerInterrupt);
  splash_init();
  clean_screen();
}

void loop()
{
  clean_screen();
  menu();
  if(game_selection==0) snake_init();
  while(game_selection==0){
		delay(snake_game_speed);
		food_snake();
		move_snake();
	}
  delay(DELAYVAL); 
}

void splash_init()
{
	char shift,j,g,i;
	if(splash_enabled == 1){
		for(g=0;g<18;g++){
			for(j=0;j<13;j++){
				write_screen(j,g,5,0,0);
				delay(12); 
			}
		}
	
		for(g=0;g<18;g++){
			for(j=0;j<13;j++){
				write_screen(j,g,0,0,0);
				delay(12); 
			}
		}
		for(i=0;i<70;i++){
			remove_sprite(11-i,4,letter_M);
			print_sprite(10-i,4,letter_M,0,0,5);
			remove_sprite(16-i,4,letter_A);
			print_sprite(15-i,4,letter_A,0,0,5);
			remove_sprite(21-i,4,letter_K);
			print_sprite(20-i,4,letter_K,0,0,5);
			remove_sprite(26-i,4,letter_I);
			print_sprite(25-i,4,letter_I,0,0,5);
			remove_sprite(31-i,4,letter_N);
			print_sprite(30-i,4,letter_N,0,0,5);
			remove_sprite(36-i,4,letter_G);
			print_sprite(35-i,4,letter_G,0,0,5);
			remove_sprite(36-i,9,letter_D);
			print_sprite(35-i,9,letter_D,0,0,5);
			remove_sprite(41-i,9,letter_E);
			print_sprite(40-i,9,letter_E,0,0,5);
			remove_sprite(46-i,9,letter_V);
			print_sprite(45-i,9,letter_V,0,0,5);
			remove_sprite(51-i,9,letter_I);
			print_sprite(50-i,9,letter_I,0,0,5);
			remove_sprite(56-i,9,letter_C);
			print_sprite(55-i,9,letter_C,0,0,5);
			remove_sprite(61-i,9,letter_E);
			print_sprite(60-i,9,letter_E,0,0,5);
			remove_sprite(66-i,9,letter_S);
			print_sprite(65-i,9,letter_S,0,0,5);
			delay(30); 
		}
  }
}

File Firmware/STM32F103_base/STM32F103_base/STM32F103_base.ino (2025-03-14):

#include <Adafruit_NeoPixel.h>
#ifdef __AVR__
 #include <avr/power.h> // Required for 16 MHz Adafruit Trinket
#endif
void SystemClock_Config(void);
static void MX_GPIO_Init(void);
static void MX_USB_PCD_Init(void);

#define PIN PA6 //pin for the PWM screen
#define string_five  0 //1 if the string is not correct. 0 if it is.
char splash_enabled = 0;
char ingame = 0; // = 1 if there is a game active.
char speed_menu = 50;
char snake_game_speed = 200;

char buttonmap = 0b00000000;	//Buttons char map
/*
0b12345678
1: Up arrow
2: Down arrow
3: Left arrow
4: Rigth arrow
5: S_b
6: S_a
7: 
8:
*/

char game_selection = 9;

char game_ram[70]={ 
     0b00000000,
     0b00000000,
     0b00000000,
     0b00000000,
     0b00000000,     
	 0b00000000,
     0b00000000,
     0b00000000,
     0b00000000,
     0b00000000,
     0b00000000,
     0b00000000,
     0b00000000,
     0b00000000,
     0b00000000,     
	 0b00000000,
     0b00000000,
     0b00000000,
     0b00000000,
     0b00000000,
     0b00000000,
     0b00000000,
     0b00000000,
     0b00000000,
     0b00000000,     
	 0b00000000,
     0b00000000,
     0b00000000,
     0b00000000,
     0b00000000,
     0b00000000,
     0b00000000,
     0b00000000,
     0b00000000,
     0b00000000,     
	 0b00000000,
     0b00000000,
     0b00000000,
     0b00000000,
     0b00000000,
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
 };

// How many NeoPixels are attached to the Arduino?
#define NUMPIXELS 234 // Popular NeoPixel ring size

Adafruit_NeoPixel pixels(NUMPIXELS, PIN, NEO_GRB);

#define TIMER_INTERRUPT_DEBUG         0
#define _TIMERINTERRUPT_LOGLEVEL_     0

#include "STM32TimerInterrupt.h"
#include "STM32_ISR_Timer.h"

#define TIMER_INTERVAL_MS         100
#define HW_TIMER_INTERVAL_MS      50

// Init STM32 timer TIM1
STM32Timer ITimer(TIM1);

// Init STM32_ISR_Timer
// Each STM32_ISR_Timer can service 16 different ISR-based timers
STM32_ISR_Timer ISR_Timer;

#define TIMER_INTERVAL_0_50mS         10L
#define TIMER_INTERVAL_0_5S           500L
#define TIMER_INTERVAL_1S             1000L
#define TIMER_INTERVAL_1_5S           1500L

void TimerHandler()
{
  ISR_Timer.run();
}

int var = 0;
char display_matrix[13][18][3] = {0};  //Display matrix

#define DELAYVAL 50 // Time (in milliseconds) to pause between pixels
int parpadeo = 0;

//----------------------------------
void buzzer_beep(char time = 0){
  time = 5;
}
// VOID read_screen
// Outcome: the intensity of the color
// Income: X and Y position. Color to be read
char read_screen(char x, char y, char color){
  if(string_five==1){
    if (y > 11 && y< 15){
      y +=3;
    } else if (y >= 15){
      y -=3;
    } 
  }
  return display_matrix[x][y][color];
}

// VOID write_screen
// Outcome: nothing
// Income: X and Y position + R, G and B color. MAX VALUE: 30 for the colors
void write_screen(char x, char y,char r,char g, char b){
  bool convertion =0;
  if(r>10) r = 10;
  if(g>10) g = 10;
  if(b>10) b = 10;

  if(string_five==1){
    if (y > 11 && y< 15){
      y +=3;
    } else if (y >= 15){
      y -=3;
    } 
  }

  if(x<13 && y <18 )display_matrix[x][y][0] = r;
  if(x<13 && y <18 )display_matrix[x][y][1] = g;
  if(x<13 && y <18 )display_matrix[x][y][2] = b;
}

//----------------------------------
// VOID clean_screen
// Outcome: nothing
// Income: nothing
void clean_screen(){
  for(char x = 0; x<13; x++){
    for(char y = 0; y<18; y++){
      write_screen(x,y,0,0,0);
    }
  }
}
//----------------------------------
// VOID update_screen
// Outcome: nothing
// Income: 0 for not cleaning. 1 will clean the display before updating.

void update_screen(bool clean = 0){
  int x=0, y=0;
  if(clean==1) pixels.clear();
  for(char i = 0; i<NUMPIXELS; i++){
    x = i % 13;
    y = i / 13;
    pixels.setPixelColor(i, pixels.Color(display_matrix[x][y][0],display_matrix[x][y][1], display_matrix[x][y][2]));
  }
  pixels.show();
}

//----------------------------------
// VOID write_color_screen
// Outcome: nothing
// Income: r, g, b. MAX VALUE 30

void write_color_screen(char r,char g,char b){
  if(r>10) r = 10;
  if(g>10) g = 10;
  if(b>10) b = 10;
  for(char x = 0; x<13; x++){
    for(char y = 0; y<18; y++){
      write_screen(x,y,r,g,b);
    }
  }
}

//COPIED DIRECTLY FROM PICBYTESMICRO
void print_sprite(char x,char y, char *sprite, char brightr = 0,char brightg = 0,char brightb = 0){
	for (char i=0; i<5; i++)
	{
    //(enable_active_state == HIGH) ? LOW : HIGH
    if(((sprite[0]>>(7-i))&1)==1)write_screen(x+i,y,brightr,brightg,brightb);
		if(((sprite[1]>>(7-i))&1)==1)write_screen(x+i,y+1,brightr,brightg,brightb);
		if(((sprite[2]>>(7-i))&1)==1)write_screen(x+i,y+2,brightr,brightg,brightb);
		if(((sprite[3]>>(7-i))&1)==1)write_screen(x+i,y+3,brightr,brightg,brightb);
		if(((sprite[4]>>(7-i))&1)==1)write_screen(x+i,y+4,brightr,brightg,brightb);
	}
}

//COPIED DIRECTLY FROM PICBYTESMICRO
void remove_sprite(char x,char y, char *sprite){
	for (char i=0; i<5; i++)
	{
    //(enable_active_state == HIGH) ? LOW : HIGH
    if(((sprite[0]>>(7-i))&1)==1)write_screen(x+i,y,0,0,0);
		if(((sprite[1]>>(7-i))&1)==1)write_screen(x+i,y+1,0,0,0);
		if(((sprite[2]>>(7-i))&1)==1)write_screen(x+i,y+2,0,0,0);
		if(((sprite[3]>>(7-i))&1)==1)write_screen(x+i,y+3,0,0,0);
		if(((sprite[4]>>(7-i))&1)==1)write_screen(x+i,y+4,0,0,0);
	}
}

//COPIED DIRECTLY FROM PICBYTESMICRO
void write_button(char buttonx){
	char new_value= 0b10000000;
	buttonx--;
	new_value = new_value >> buttonx;
	buttonmap = buttonmap|new_value;
}

//COPIED DIRECTLY FROM PICBYTESMICRO
char read_button(char buttonx){
	char answer = 0b00000000;
	answer = buttonmap >> (8-buttonx);
	answer = answer&0b00000001;
	return answer;
}

//COPIED DIRECTLY FROM PICBYTESMICRO
void clean_buttons(void){
	buttonmap=0;
}

void update_buttons(void){
	if(digitalRead(PA0)==LOW) write_button(1); // Up
	if(digitalRead(PA1)==LOW) write_button(2); // Down
	if(digitalRead(PA3)==LOW) write_button(3); // Left
	if(digitalRead(PA2)==LOW) write_button(4); // Right
	if(digitalRead(PA4)==LOW) write_button(5); // B
	if(digitalRead(PA5)==LOW) write_button(6); // A

}

void TimerInterrupt()
{
  update_screen(1);
  if(game_selection==0)snake_check_movement();
  if(ingame==1) clean_buttons();
	update_buttons();
}

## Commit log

2024-06-20 Preliminar Bill Of Materials
    [PixelBytesBOM_v0.1.xlsx]
2024-06-20 First project and library for the ICleds
    [pixelbytes.kicad_pcb, pixelbytes.kicad_sch]
2024-06-24 First V0.1 version. Ordering the PCB to @PCBWAY in a couple of days
    [ICLEDstring1.kicad_sch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]
2024-09-22 New version of PixelBytesHost
    [BatteryCharger.kicad_sch, BatteryCharger.sch, Dpad.kicad_sch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]
2024-09-22 New intro for github
    [PixelBytesHost-B_Cu.gbr, PixelBytesHost-B_Mask.gbr, PixelBytesHost-B_Silkscreen.gbr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]
2024-09-26 New firmware for the board
    [PixelBytesHost-B_Cu.gbr, PixelBytesHost-B_Mask.gbr, PixelBytesHost-B_Silkscreen.gbr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]
2024-10-16 Demo binary for the board
    [BatteryCharger.kicad_sch, PixelBytesHost.kicad_sch]
2024-11-07 Subimos todos los archivos de la v0.25
    [BatteryCharger.kicad_sch, Dpad.kicad_sch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]
2024-12-04 Host HW 1.0 finished
    [PixelBytesHost-B_Cu.gbr, PixelBytesHost-B_Mask.gbr, PixelBytesHost-B_Silkscreen.gbr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]
2025-02-20 New Version PixelBytesHost
    [Dpad.kicad_sch, PixelBytesBOM_v1.25.xlsx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]
